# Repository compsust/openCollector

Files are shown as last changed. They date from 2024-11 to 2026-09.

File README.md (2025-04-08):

# OpenCollector - Open Source Data Collection

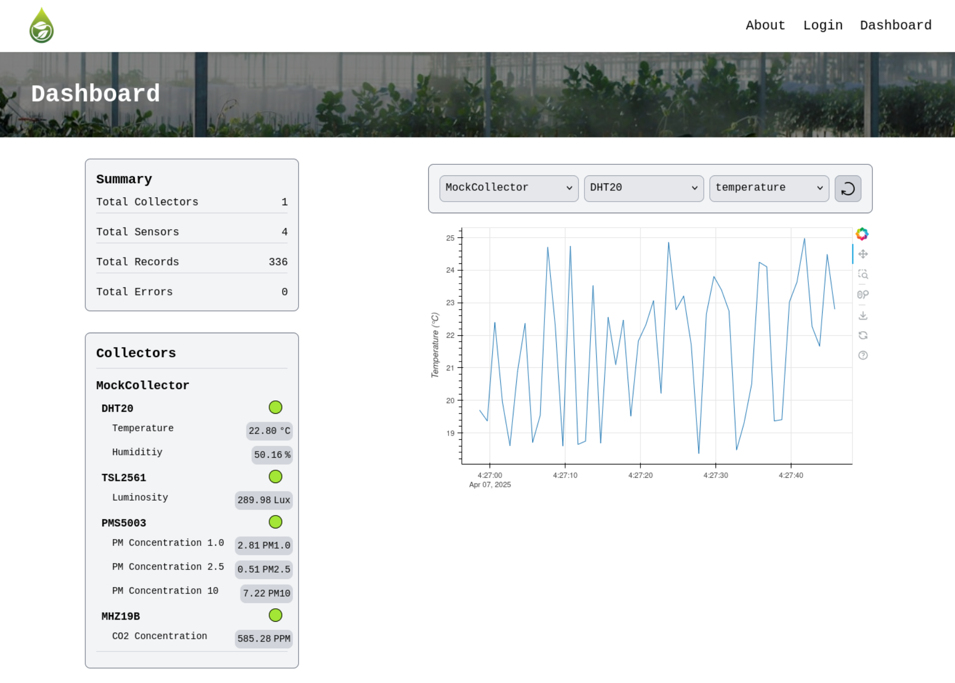
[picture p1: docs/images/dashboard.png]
Alt: a screenshot of the data monitoring dashboard


<div  align="center">
    <a href="https://compsust.fas.sfu.ca/openCollector/">
        <b>Documentation</b>
    </a>
</div>
</br>

OpenCollector is an open source Raspberry-Pi based data collection platform. Partnered with the [Simon Fraser University Computational Sustainability Lab](https://compsust.fas.sfu.ca/), this project is intended to create the foundation for a user-friendly IoT system that allows individuals and organizations to safely measure the impacts on their environment and monitor them for analysis and forecasting.

This prototype allows users to identify various parameters in their environment (such as temperature, light intensity, carbon dioxide) and tracks and displays the trends over time. This data is then securely stored in a cloud storage database to be able to access at a later date. While this prototype focuses on the use in a greenhouse, this project is intended for various uses.

## Usage and Development

Refer to [the documentation](https://compsust.fas.sfu.ca/openCollector/) for instructions on how to use and contribute to the project.

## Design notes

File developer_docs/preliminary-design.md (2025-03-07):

# Preliminary Software Design Document

This is the first software design document that is trying to establish what Python modules will be required and how they will interact with eachother. To start with, here is a brief overview of a principal used for design.

## Abstract Interfaces

In software engineering, an interface is a piece of code that contains only specification. For example, a function may define the arguments it accepts, the type of value it returns, and have a documentation string, but the actual workings of the function are left blank. The advantage of using interfaces is that it allows seperate pieces of software to be agnostic to specific implementations of the code they depend on, by making them depend on a contract instead. This allows changing those pieces independently. If one piece of the software changes, the changes required to make the rest of the system interact with the new logic should be as limited as possible to the location of the relevant change.

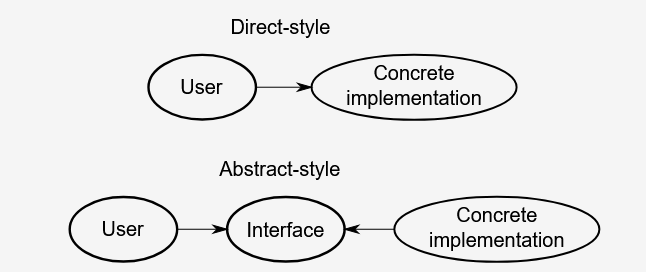
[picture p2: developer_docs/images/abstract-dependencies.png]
Abstract Interfaces Diagram


Abstract classes may be implemented with Python's `abc` (abstract base class) or `Protocol` types.

## Manager/Driver Design Pattern

The design pattern in use here can be called the Manager/Driver pattern. In this pattern, manager classes are responsible for implementing the main logic of the program, with the core control loop having access to all the manager classes it needs to acomplish its tasks, and deferring most of the logic to them. Manager classes focus more on high-level orchestration logic such as coordinating tasks whereas driver classes focus on low-level logic such as interfacing with hardware.

Manager classes may contain multiple driver classes which it uses to complete tasks. If required, the driver classes may be made to implement an abstract interface, such that the manager need not know the underlying workings of the driver. For example, the SensorManager class is what the main control loop of the program uses to retrieve sensor data. The SensorManager contains multiple SensorDriver classes, which each implement an AbstractSensorDriver interface. Because of this, if a new sensor is to be supported, this should not involve any changes to the SensorManager class, as it is only responsible for coordinating instances of classes which implement the AbstractSensorDriver interface. Therefore, only a new implementation of the AbstractSensorDriver interface would need to be created.

## Collector Node Design

This section goes over the software architecture of the collector node. A summary of this architecture is given in the following image.

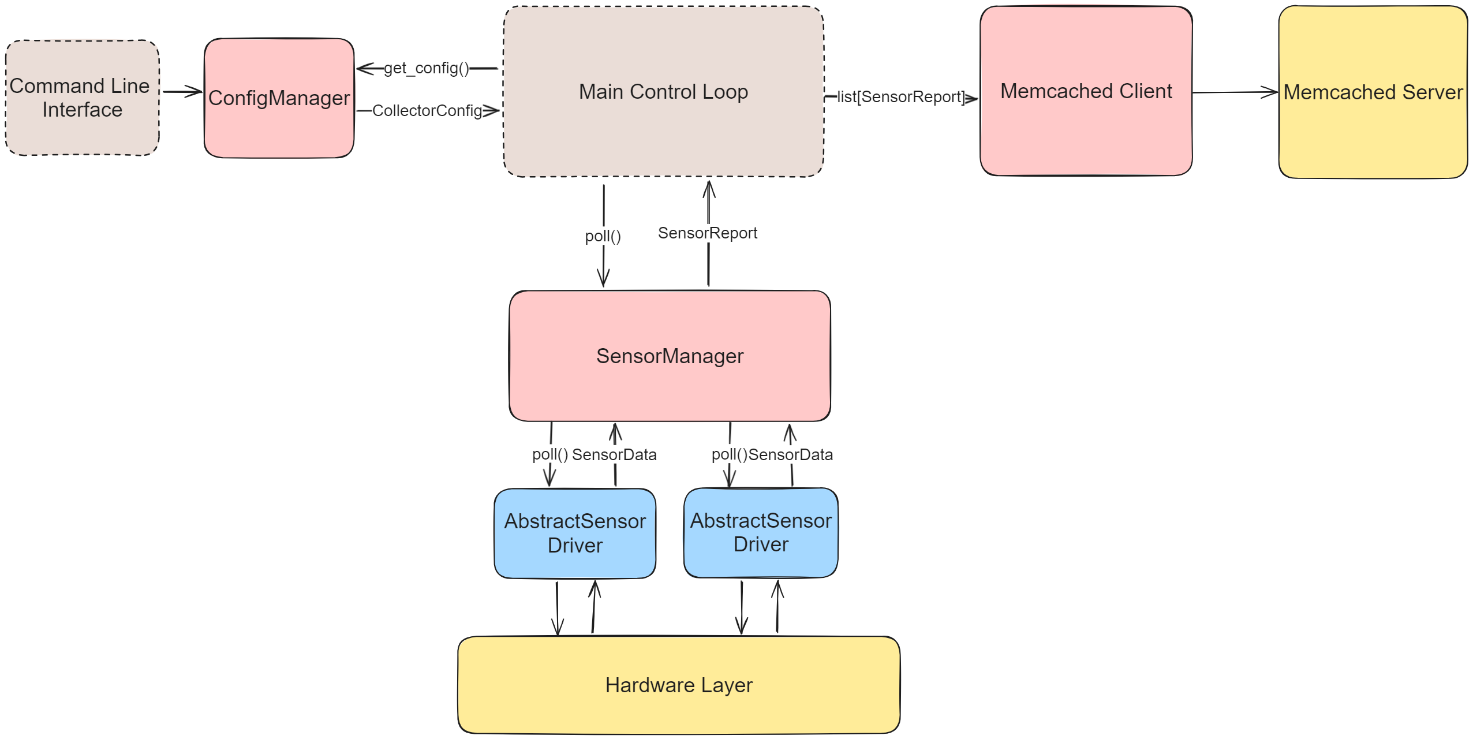
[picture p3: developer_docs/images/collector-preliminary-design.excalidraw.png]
Collector Node Design


### Classes

This section gives an overview of the components of the system.

#### Sensors

The `SensorManager` class is responsible for controlling each `SensorDriver` class it is connected to, and constructing a `CollectorReport` object. This will involve the following methods:
- `SensorManager.init()`: Given a `CollectorConfig` object, initializes a `SensorDriver` class for every sensor in the config. There will be a lookup table mapping types of sensor configurations to implementations of the `AbstractSensorDriver` interface which the `SensorManager` can use.
- `SensorManager.poll()`: Calls the `poll()` method on each of the underlying drivers, retrieving the data, catching any exceptions, and constructing a `CollectorReport` object to return to the main control loop.

The `AbstractSensorDriver` class is resposible for collecting data from the hardware and will contain the following methods:
- `SensorDriver.init()`: Given a `SensorConfig` object, initializes any underlying library with the configured values.
- `SensorDriver.poll()`: Calls the underlying sensor library to return a `SensorData` object.

#### Data Caching

This class will wrap an instance of the memcached client and allow the collector node to push data.

This class will simply have one method which stores any given data in the memcached client.
- `CacheManager.cache()`: Stores the data in-memory.

#### Configuration

The `ConfigManager` serves to make changes to the configuration file in a consistent way. If the configuration file is updated manually, there is no way to enforce constraints, such as GPIO pin numbers being correct.
- `ConfigManager.add_sensor()`: Adds a `SensorConfig` to the configuration file.
- `ConfigManager.update_sensor()`: Updates a `SensorConfig` in the configuration file.
- `ConfigManager.delete_sensor()`: Removes a `SensorConfig` from the configuration file.
- `ConfigManager.add_target()`: Adds a `TargetConfig` to the configuration file.
- `ConfigManager.update_target()`: Updates a `TargetConfig` in the configuration file.
- `ConfigManager.remove_target()`: Removes a `TargetConfig` from the configuration file.

### Data Structures

This section outlines the data structures that will need to be used and passed around the various components.

#### Sensor Data

These datastructures may utilize Python's dataclasses.

- `SensorData`: Generic data type for data returned by a sensor. May just be an alias for `Dict[str, Any]`.
- `CollectorRecord`: Contains a `SensorData`, the ID of the associated sensor, and a `datetime` timestamp.
- `CollectorError`: Contains an error code, an error message, the ID of the associated sensor, and a `datetime` timestamp.
- `CollectorReport`: Contains a list of `CollectorRecord`, a list of `CollectorError`, and the ID of the collector node.

#### Configuration Data

These datastructures may utilize the Pydantic library to make declarative validation easy. 

- `SensorConfig`: Contains an enumerated value describing the type of sensor, a sensor ID, and a dictionary containing any device-specific configuration values, such as GPIO pins and settings passed into the underlying sensor library.
- `TargetConfig`: Contains an ID of a storage node that data is to be sent to, and an endpoint where the data can be sent over the network.
- `CollectorConfig`: Contains a list of `SensorConfig`, a list of `TargetConfig`, and a collector node ID.

### Program Logic

#### Startup

Upon program startup, the main control loop does the following:
1. Instances of all required Manager classes are created.
2. The main control loop retrieves the device configuration by calling `ConfigManager.get_device_config()`. This configuration data contains all sensors that are currently configured on the device. For each sensor, the `SensorManager` initializes the corresponding `SensorDriver` class.

#### Polling

On an interval known as `POLLING_INTERVAL`, the following occurs:
1. The main control loop calls `SensorManager.poll()` which in turn calls `AbstractSensorDriver.poll()` on all the `SensorDrivers`. Each `SensorDriver` may return a `SensorData`, or it may raise an exception if an error has occurred. If it raises an exception, the `SensorManager` catches it and creates a `CollectorError` object. If it returns data, the `SensorManager` creates a `CollectorRecord`.
2. The `SensorManager` creater a `CollectorReport` object with the `CollectorRecord` and `CollectorError` objects, and populates it with the list of target storage node IDs that the device is to send data to. This is to allow the device to keep track of which of its targets it has sent data to, in the case that data is attempted to be sent when some connections are offline.
3. Finally, the `SensorManager` returns the `CollectorReport` object to the main control loop, which then calls `CacheManager.cache()` which stores the data in-memory.

## Storage Node Design

This section goes over the software architecture of the storage node. A summary of this architecture is given in the following image.

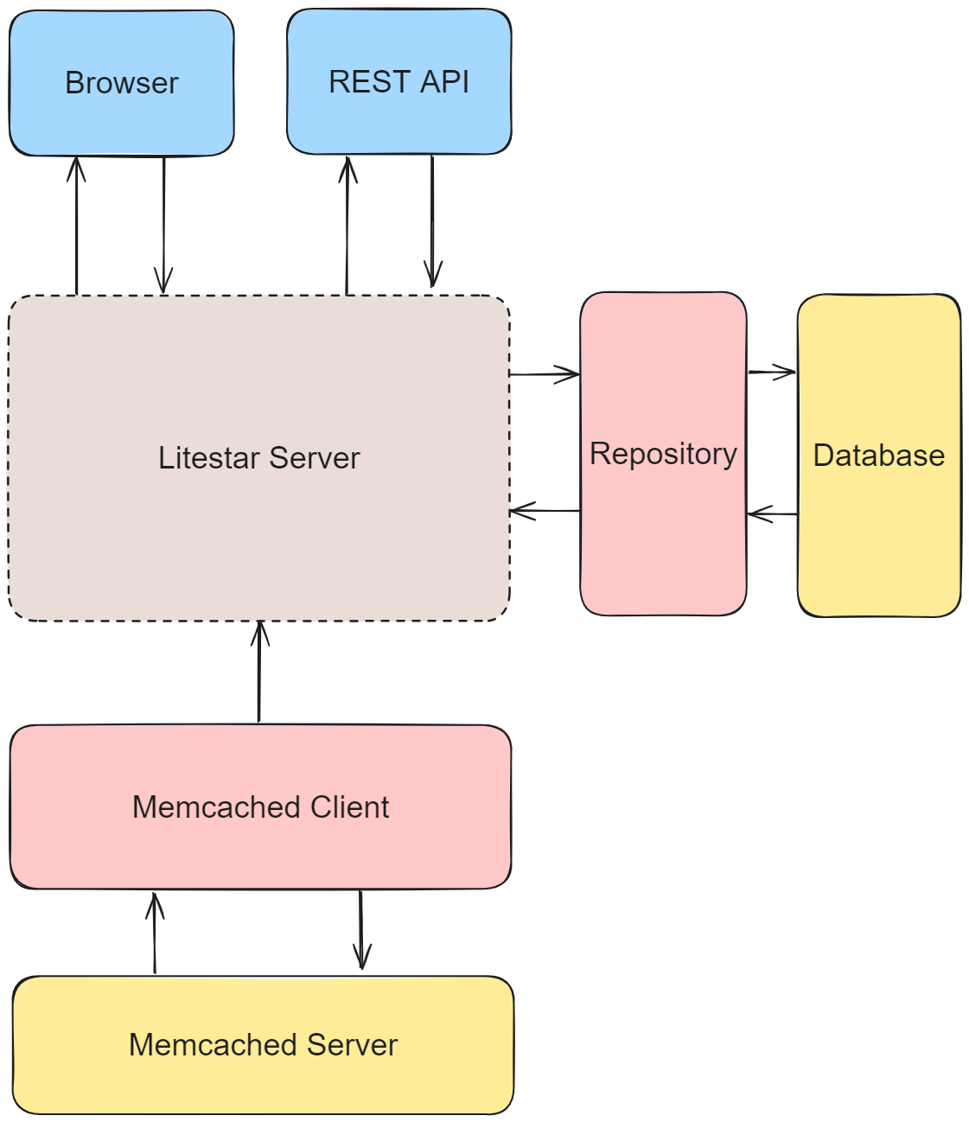
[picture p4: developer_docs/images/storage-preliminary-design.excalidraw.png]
Storage Node Design


### Classes

This section gives an overview of the components of the system.

#### Memcached Client/Server

The Memcached server is what is connected to the network and collecting the data cached by all connected collector nodes. It is run in a seperate process to the main Litestar server. The Memcached client is a construct initialized on the Litestar server which interacts with the Memcached server and pulls data from it. Via a regular task, the Litestar server pulls data from the Memcached server where it then stores it into persistent storage.  

#### Repository/Database

The database is the persistent storage mechanism and may be a SQL database such as Postgres or a no-SQL database such as MongoDB. The Litestar server should be agnostic to the underlying database technology through the use of the Repository class, which converts between database constructs and native application datatypes such as `CollectorReport`.

#### Litestar Browser & REST Interface

The Litestar app exposes two types of routes: those which return HTML and make up the interactive browser based user-interface, and those which return JSON which make up the REST API.

The browser app may make use of templating libraries such as Jinja2 to construct the HTML to be sent to the browser. With this approach, the HTML page is sent upon every request to the server in the style of a multi-page-app, and a library such as HTMX can be used to surgically update HTML elements to provide page updates without refreshes. However, if more complicated behavior is required, a javascript framework which can compile to HTML and JS such as the Svelte framework may be used instead.

The REST API will implement the REST standards for API development and thus represent collector and sensor data as resources to be queried via GET requests.

Both the API and browser app will use session authentication. An admin user will be created upon initialization of the storage node, and this admin user may create more users through a configuration page, bypassing the need for user registration.

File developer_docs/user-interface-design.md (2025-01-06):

# User Interface Design

This document summarizes the wireframes that were made to draft the user interface.

The wireframes follow this hierarchical structure for accessing in the browser:

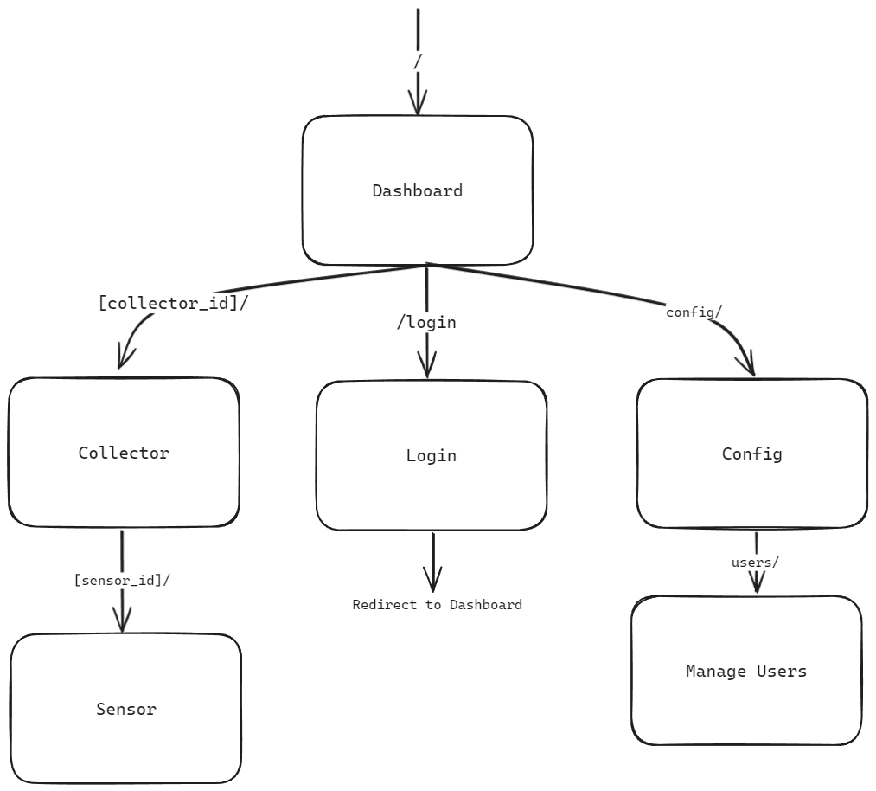
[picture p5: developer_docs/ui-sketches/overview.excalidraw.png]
Page Structure


The dashboard provides quick access to all information and a graph:

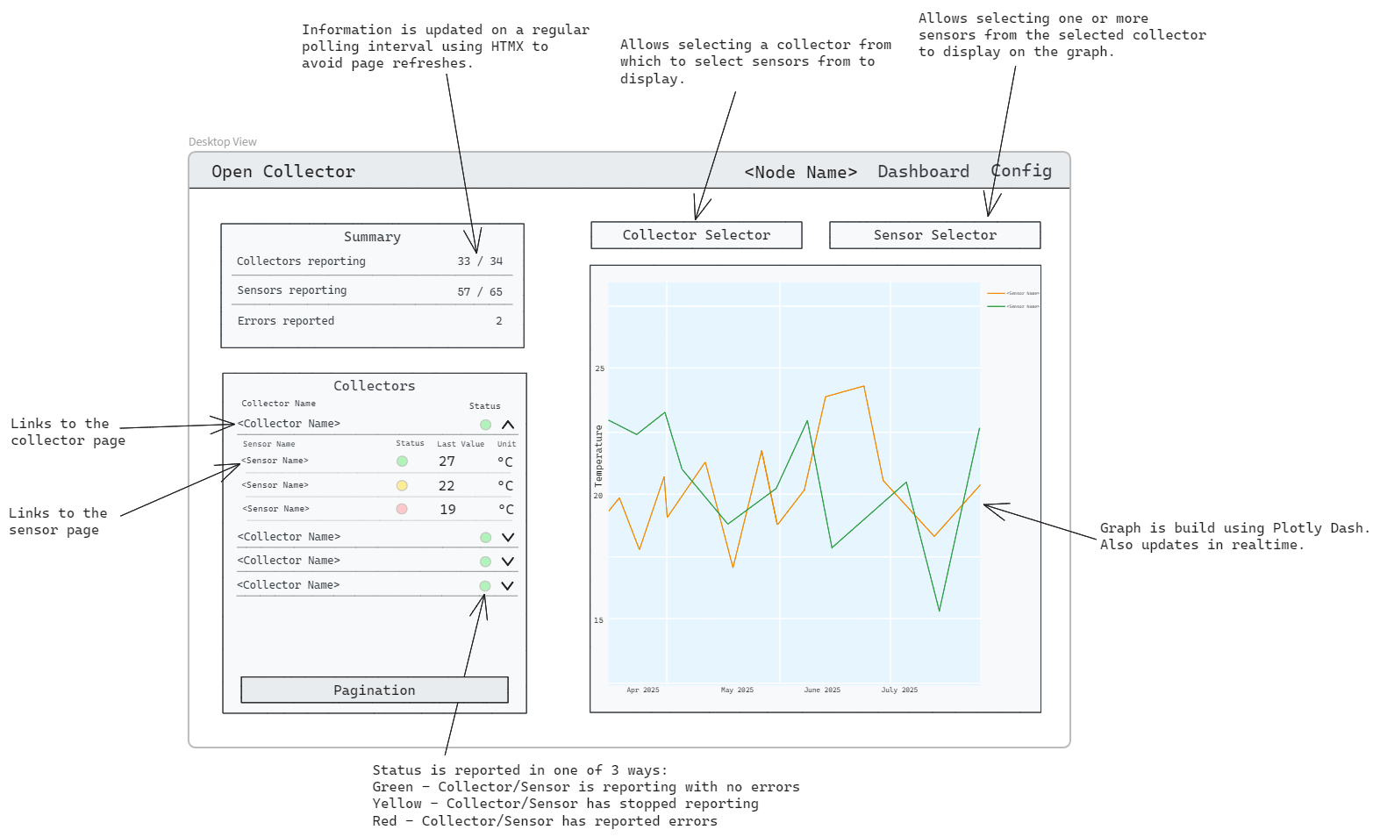
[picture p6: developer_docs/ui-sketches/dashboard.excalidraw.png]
Dashboard


The login page is used to authenticate the user. There is an admin user setup upon initialization of the storage node and more users can be configured by the admin user. If an unauthenticated user visits any page other than the login page, they are redirected to the login page. Upon successful login, the user is redirected to the login page.

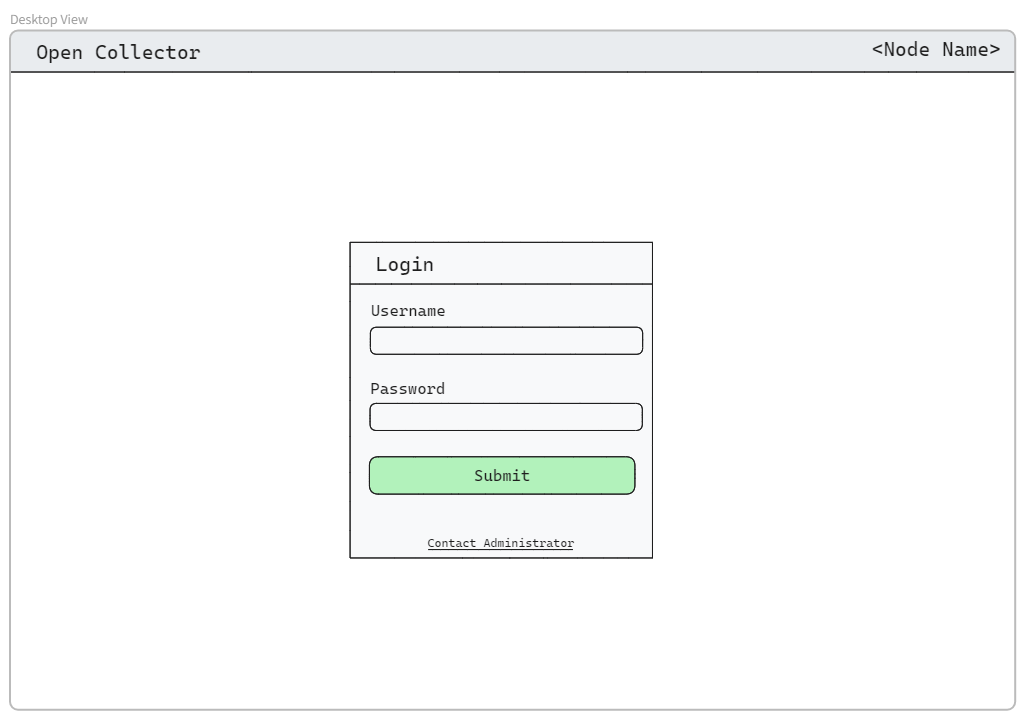
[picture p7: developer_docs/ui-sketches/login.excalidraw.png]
Login


Each collector has its own page, showing its details, sensors, and errors.

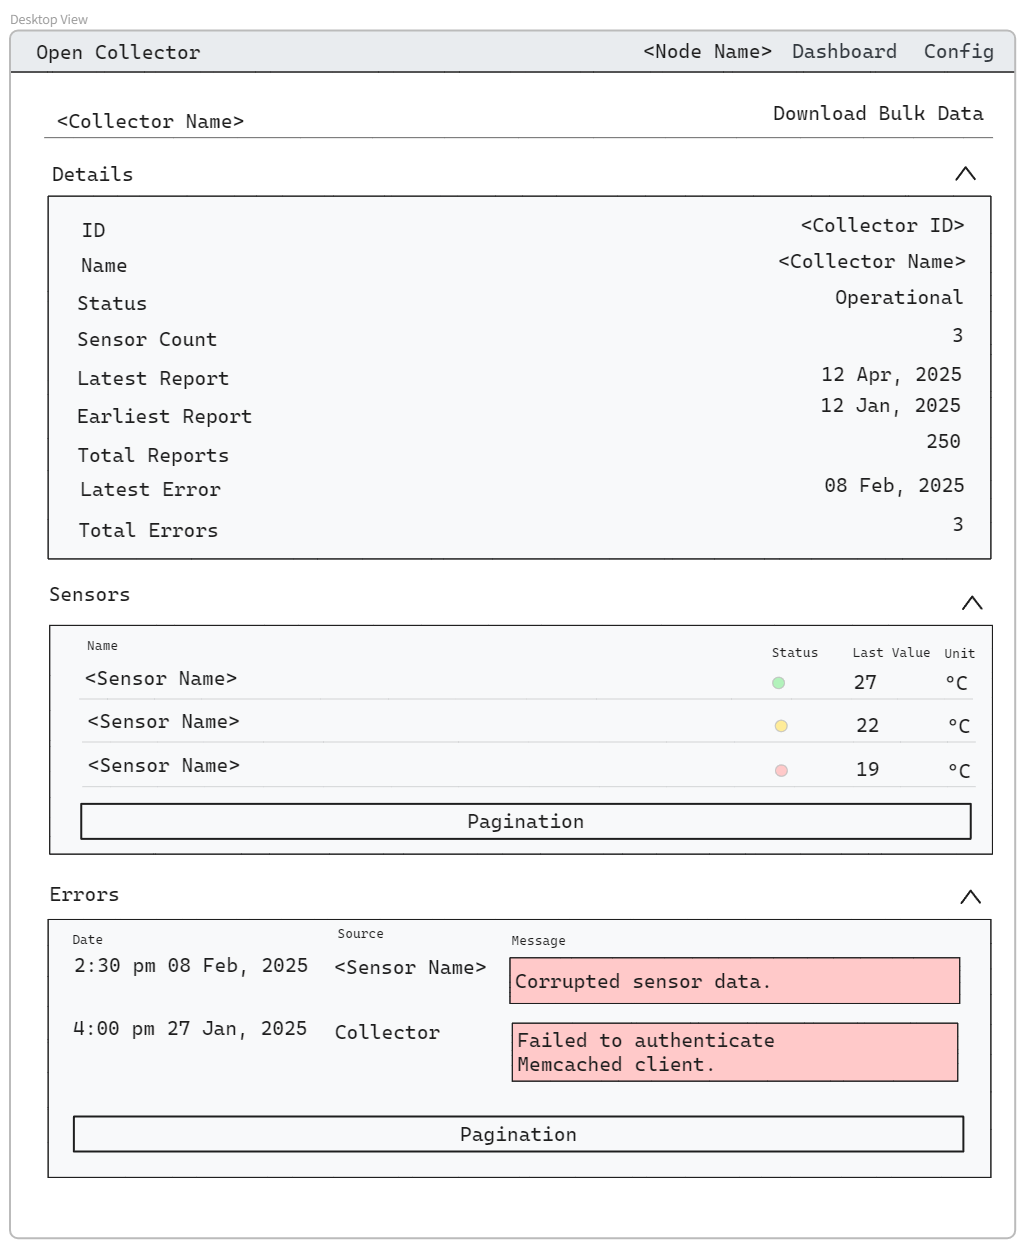
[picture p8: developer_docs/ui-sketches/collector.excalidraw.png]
Collector


Each sensor has its own page, showing its details, records, and errors.

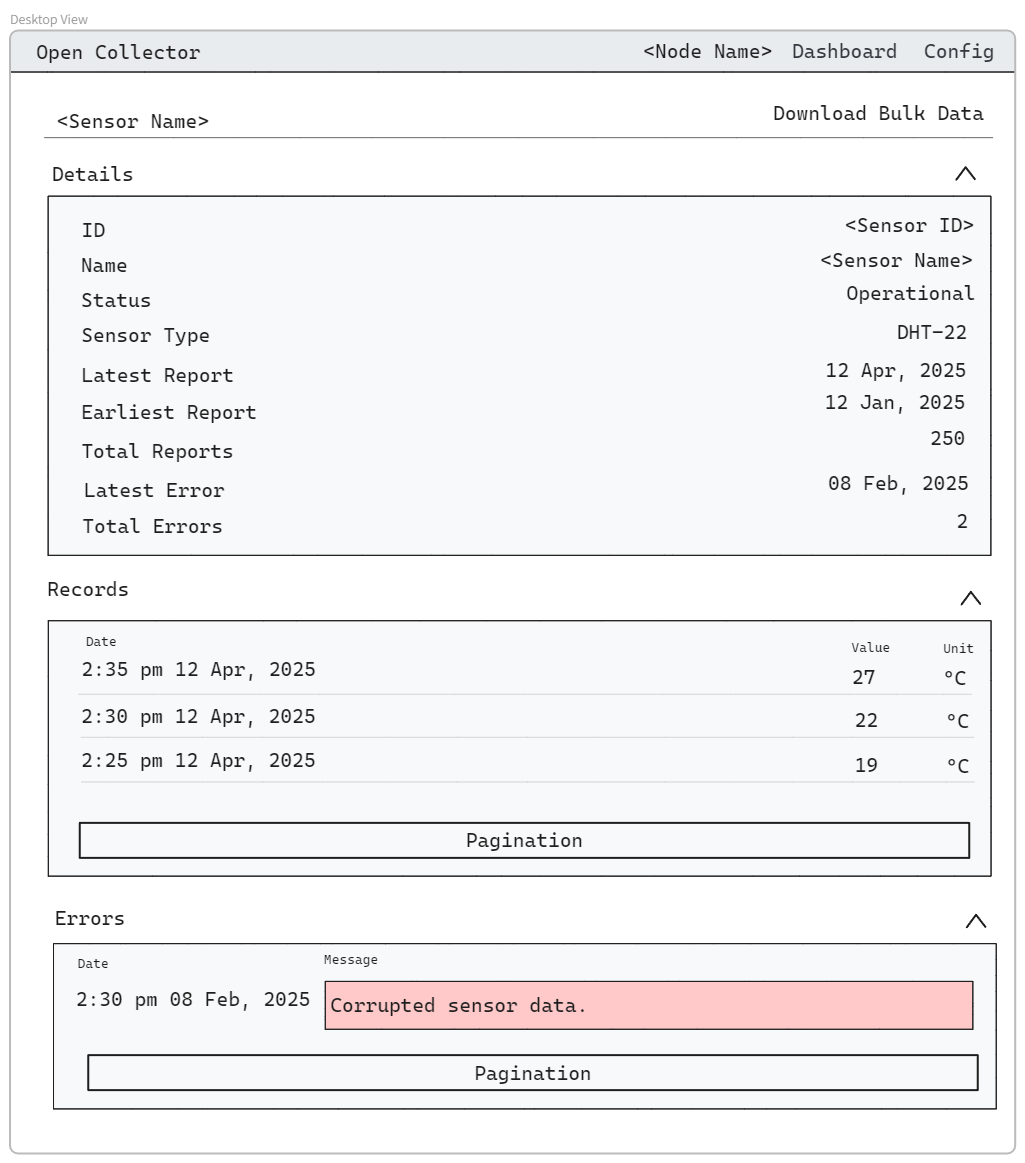
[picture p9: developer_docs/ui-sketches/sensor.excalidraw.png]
Sensor


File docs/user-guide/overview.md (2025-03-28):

# User Guide

This section of the documentation provides instructions for setting up and using the OpenCollector system to collect data.

## Identify Devices

The first step to deploying the OpenCollector stack is to determine which devices will be hosting which services. The following considerations apply.

- **Collector** nodes may be deployed on any device capable of reading from sensors and connecting to the internet. All collector code is compatible with *[micropython](https://micropython.org/)*, meaning the collector program may be run on a compatible microcontroller such as a Raspberry Pi Pico W. 
- **Storage** nodes may be deployed on any device that is capable of hosting a webserver. It may be run on the same device as the collector node, provided that the collector node is not running using *micropython*, as the storage node code is not compatible with *micropython*.
- **QuestDB** may be hosted on the same device as the **Storage** node, however the device must be capable of storing the desired volume of data at the desired intake bandwidth. If a large amount of data is to be stored, or many simultaneous collector streams are required, it may be best to host the database instance on a seperate device or on the cloud.

A list of which sensors are supported by the software is contained within the [Sensors](./collector/sensors.md) page. 

### Network Considerations

The database is required to be reachable over the network by both the collector and storage nodes. The collector nodes use *HTTP* to upload their data, and the storage node uses *HTTP* to display the user interface in the browser. The storage node uses the *PostgreSQL* protocol for reading data from the database, which by default uses *TCP/IP*.

## Deploy QuestDB and Storage Node

QuestDB and the storage node may be deployed together or seperately. The instructions included below support deploying them through *Docker* or through manual installation.

### Together

The following instructions are for self-hosting QuestDB together along with the storage node on the same device.

#### Docker

*TODO*

#### Manually

*TODO*

### Seperate

The following instructions are for hosting QuestDB seperately from the storage node.

#### QuestDB

Instructions for installing QuestDB are included in its [documentation](https://questdb.com/docs/quick-start/#install-questdb).

#### Docker

*TODO*

#### Manually

*TODO*

## Assemble Collectors

The wiring used to connect each collector node to its sensors, as well as how each collector node is situated in its environment, does not affect the operating of the system and thus may be achived however the user wishes. However, this project includes both a PCB that may be used to facilitate clean wiring of multiple sensors to a Raspberry Pi Pico W, as well as a 3D printable enclosure. See the [PCB and Enclosure](./collector/pcb.md) page for more information. 

## Configure Collectors

Each collector must be configured with the information required to connect to its sensors and upload its data. See the [Collector Config](./collector/config.md) for information on how to configure a collector.

## Deploy Collectors

*TODO*

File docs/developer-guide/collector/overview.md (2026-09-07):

# Collector Development

The main goals of the collector code are as follows:

- Be flexible in supporting the addition of new types of sensors to the software.
- Provide enough configuration options to support all use cases without modifying the source code.
- Support Micropython.

## Architecture

The architecture of the collector code is visualized below and contains the following modules:

- **Main Control Loop** - This is the entrypoint of the program and is responsible for orchestrating the modules and the endless loop.
- **`ConfigManager`** - This class is responsible for parsing and validating the configuration contained within `config.json`.
- **`UploadManager`** - This class is responsible for formatting the collected data and uploading it via HTTP to the configured QuestDB endpoint.
- **Sensor Polling**:
    - **`SensorDriver`** - Each `SensorDriver` class instance is responsible for collecting data from a single sensor.
    - **`SensorManager`** - This class is responsible for initializing as many `SensorDriver` instances as are called for in the configuration, polling them, and sending the data to the main control loop.

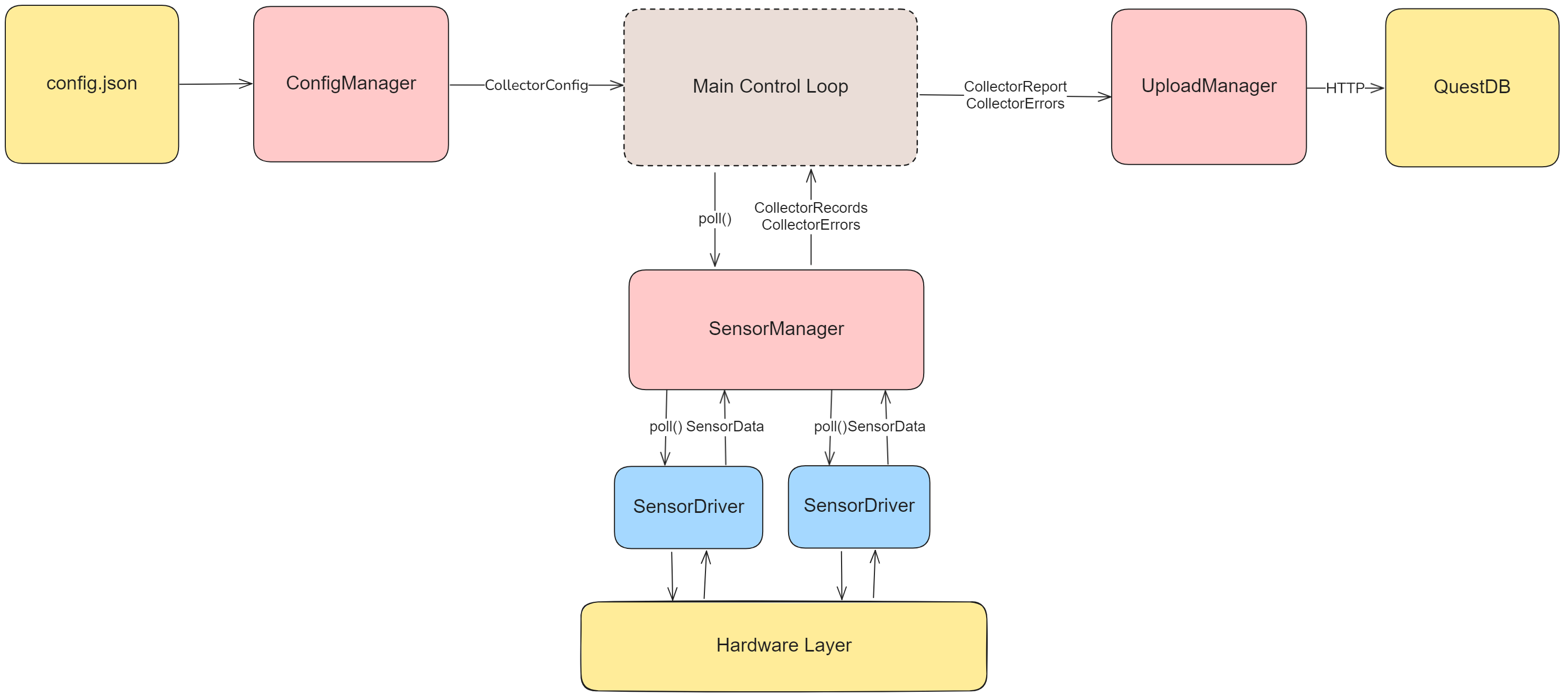
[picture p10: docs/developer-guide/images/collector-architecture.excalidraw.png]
Alt: the diagram visualizes the ConfigManager sending the configuration to the main control loop, the SensorManager polling multiple SensorDrivers which each communicate with the hardware layer, and the UploadManager sending the data to the QuestDB database


### Main Control Loop

The main control loop has the following behavior:

1. Initializes all required manager classes.
2. Updates the metadata tables in the database with the currently collector and sensor configuration.
3. On an endless loop:
    1. Collects sensor data.
    2. Uploads sensor data.
    3. If the upload fails, logs the exception locally and proceeds to the next cycle; the failed report is not retried.
    4. Waits for the configured `polling_interval`, expressed in milliseconds.

```mermaid

stateDiagram-v2
    [*] --> Initialization

    Initialization --> Metadata : Success
    Metadata --> Poll: Success
    Initialization --> Error : Failure
    Metadata --> Error : Failure
    Poll --> Upload
    Upload --> Wait
    Wait --> Poll : After Polling Interval

    Metadata: Metadata Upload
    Upload: Data Upload
```

### Config

For documentation on what the configuration values do, see the [User Guide](../../user-guide/collector/config.md).

See the [Config Reference](./reference/config.md) for documentation on the configuration-related source code.

### Upload

For documentation on the structure of the database, see the [Storage Database](../storage/database.md) page.

See the [Upload Reference](./reference/upload.md) for documentation on the upload-related source code.

### Sensors

For documentation on which sensors are currently supported and how to configure them, see the [User Guide](../../user-guide/collector/sensors.md) sensors page.

For instructions on how to add support for new sensors, see the [Sensor](./sensors.md) page.

See the [Sensor Reference](./reference/sensors.md) for documentation on the sensor-related source code.

#### Architecture & Approach

As the main goal of the sensor code design was to support adding more sensors in the future, the sensor code follows a manager-driver pattern, with the driver code fulfilling an abstract interface.

In software engineering, an interface is a piece of code that contains only specification. For example, a function may define the arguments it accepts, the type of value it returns, and have a documentation string explaining its behaviour, but the actual workings of the function are left blank. The advantage of using interfaces is that it allows seperate pieces of software to be agnostic to specific implementations of the code they depend on, by making them depend on a contract instead. This allows changing those pieces independently. If one piece of the software changes, the changes required to make the rest of the system interact with the new logic should be as limited as possible to the location of the relevant change.

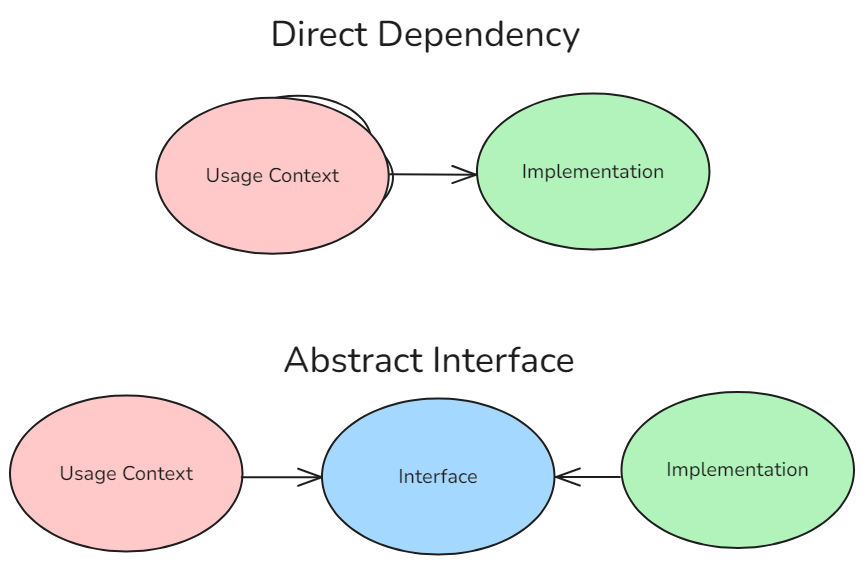
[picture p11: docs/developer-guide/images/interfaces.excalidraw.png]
Alt: the use of abstract interfaces is visualized by the usage context and the implementation both being dependent on the same dependency, as oppsed to the usage context being directly dependent on the implementation


In practice, this means that that the `SensorManger` class is not directly dependent on any specific implementation of a sensor but is instead dependent on an interface called `AbstractSensorDriver`. As long as the interface is properly designed, the changes to the codebase required to add new sensors to the software should be isolated to the creation of new implementations of the interface.

Abstract classes are be implemented with Python's `Protocol` type.

## Development

The collector is designed to run under both CPython and MicroPython. Packaging is automated, while deployment on physical hardware remains experimental and must be validated with the target sensors and firmware.

For development on a Raspberry Pi Pico W:

1. Flash a current Pico W MicroPython firmware image using the [Raspberry Pi documentation](https://www.raspberrypi.com/documentation/microcontrollers/micropython.html).
2. Copy `collector/src/config.example.json` to `collector/src/config.json` and replace the example IDs, network credentials, database address, GPIO assignments, and sensor settings.
3. Install `mpremote`, connect one board, and run `./scripts/flash_pico.sh collector/src/config.json` from the repository root.
4. Reset the board while a serial console is attached. Confirm initialization, metadata upload, repeated polling, and error reporting before disconnecting it.

Keep secrets and deployment-specific configuration out of version control. When changing collector code, test configuration parsing and sensor drivers under CPython first where practical, then repeat the test on real MicroPython hardware: module availability, filesystem paths, timing, and networking behavior differ between the runtimes.

The **Pico W package** workflow validates the canonical on-device layout without hardware. The manually dispatched **Pico W hardware-in-the-loop** workflow requires a self-hosted runner labelled `self-hosted`, `micropython`, and `pico-w`, plus a `PICO_CONFIG_JSON` repository secret. Record the MicroPython firmware version and attached sensor models with each physical test run.

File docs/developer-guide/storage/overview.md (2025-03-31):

# Storage Development

The main goals of the storage code are as follows:

- Provide a simple UI for reading the data returned by the collector nodes.
- Be stateless, such that multiple storage nodes can access the same database.

## Architecture

The architecture of the storage code is visualized below and contains the following modules:

- **Litestar** - The API framework in use for serving the browser and API interfaces.
- **Database** - This section contains code for initializing the database connection, structuring the tables, and querying the data.
- **API** - This section uses the Litestar framework to expose the database queries over a REST API.
- **Browser** - This section uses the Litestar framework to serve a visual user interface to browsers which updates in realtime.  

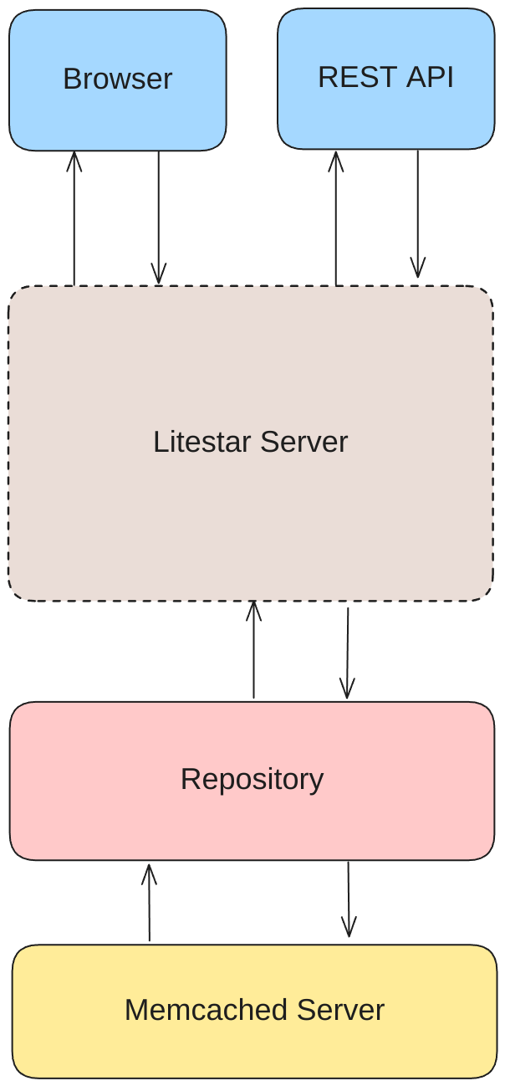
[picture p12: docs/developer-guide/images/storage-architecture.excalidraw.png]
Alt: the diagram visualizes the Litestar server reading data from the database and exposing it to a REST API and browser interface.


### Litestar

See the [Litestar documentation](https://litestar.dev/) for information on the web server framework in use

### Database

The database 

### API

### Browser

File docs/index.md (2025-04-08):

# OpenCollector - Open Source Data Collection

Alt: a screenshot of the data monitoring dashboard

OpenCollector is an open source Raspberry-Pi based data collection platform. Partnered with the [Simon Fraser University Computational Sustainability Lab](https://compsust.fas.sfu.ca/), this project is intended to create the foundation for a user-friendly IoT system that allows individuals and organizations to safely measure the impacts on their environment and monitor them for analysis and forecasting.

This prototype allows users to identify various parameters in their environment (such as temperature, light intensity, carbon dioxide) and tracks and displays the trends over time. This data is then securely stored in a cloud storage database to be able to access at a later date. While this prototype focuses on the use in a greenhouse, this project is intended for various uses.

The project encompasses the following parts:

1. Python code for collecting data from multiple sensors and uploading it to a database.
2. Python code for reading from a database and visually displaying data.
3. A PCB for wiring up a Raspberry Pi Pico W to a temperature, humidity, particulate matter, light, and CO2 sensor.
4. A 3D printable enclosure for securing the PCB.

## Documentation

See below for how to use this documentation:

- User Guide:
    - [Usage Instructions](./user-guide/usage.md): Instructions on how to use the system.
    - [Setup Instructions](./user-guide/setup.md): Instructions on how to set up the system.
- [Developer Guide](./developer-guide/overview.md): Technical details and design. 

## System Architecture

The OpenCollector system contains two main modules:      

1. **Collector Nodes** are the edge devices responsible for collecting data from sensors and uploading it to the database.
2. **Storage Nodes** are the cloud devices responsible for reading data from the database and displaying it in a cloud platform.

Additionally, the following pieces are required for the OpenCollector system to work:

- **[QuestDB](https://questdb.com/)** is used as the open-source timeseries database and is the glue between the collector and storage nodes.

Given a machine that is compatible with hosting a webserver and connecting to sensors, these modules may be run on the same device. If desired, they can be run on seperate devices, with the storage node and database on the same device or different devices, and the collector node run on an edge device connected to sensors.

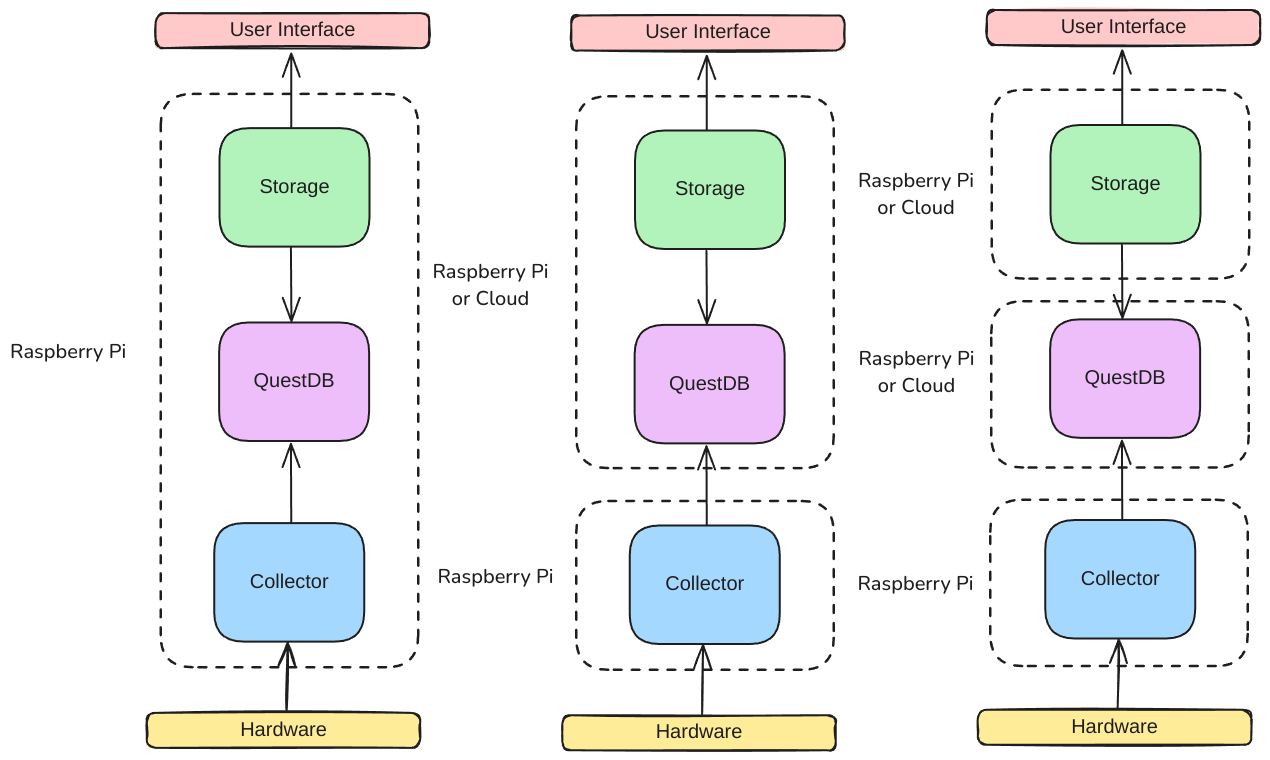
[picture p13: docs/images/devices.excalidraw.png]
Alt: a diagram visualizes that the collector, database, and storage nodes may be run on seperate or the same device.


Nodes may be connected together under the following rules:

1. Collector nodes have a single QuestDB database as a target.
2. An unlimited number of collector nodes may send data to a single QuestDB database.
3. An unlimited number of storage nodes may read data from a single QuestDB database.

This allows for any number of collector nodes to be used with a single database. While multiple storage nodes can be connected to a single database, since their only purpose is to display data, there may not be an advantage to this. Currently, a collector node can only send data to one database at a time.

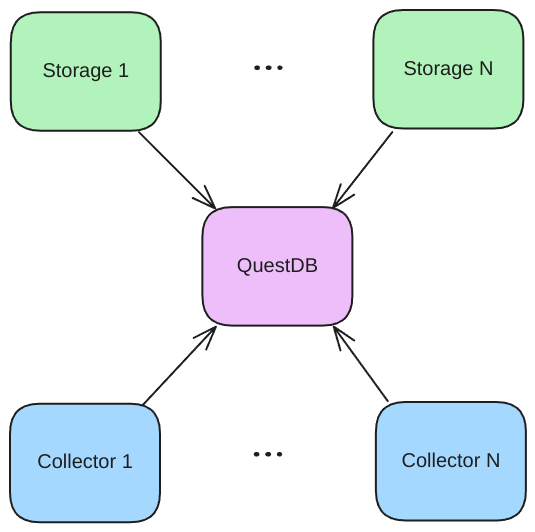
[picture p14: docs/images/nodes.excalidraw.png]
Alt: a diagram visualizes that any number of collectors and storages nodes can be connected to a single database
.

## Dependencies

This project makes use of the following dependencies:

- [Raspberry Pi](https://www.raspberrypi.com/) is used as the basis for computing, though the system should work with other hardware.
- [Python](https://www.python.org/) is used for all programming.
- [Micropython](https://micropython.org/) is used to write microcontroller compatible code for the collector node.
- [QuestDB](https://questdb.com/) is used as an open-source timeseries database.
- [Litestar](https://litestar.dev/) is used to create the REST API and browser user-interfaces.
- [HTMX](https://htmx.org/) for real-time HTML updates in the browser interface.
- [Material for MkDocs](https://squidfunk.github.io/mkdocs-material/) is used to create this documentation site.

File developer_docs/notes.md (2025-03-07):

Will want to create a readthedocs for this as well

Explain all the steps for supporting a new sensor:
1. Add a new value to SensorCodeEnum
2. Add a new entry to sensor_metadata
3. Create a new SensorDriver in the src/collector/sensors/drivers folder
4. Add this SensorDriver to the sensor_drivers dict in sensor_codes.py
5. Add the sensor config to config.json

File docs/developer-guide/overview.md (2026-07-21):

# Overview

Overall, the OpenCollector system is made up of two components:

1. A Python / Micropython program which reads sensor data and uploads it to a database on a loop.
2.  A Python webserver which reads data from the database and exposes it to a REST API and browser interface.

This developer guide provides technical details on how these components are set up and instructions on how to work on the codebase.

See the documentation sections for each sub-project:

- [Collector](./collector/overview.md)
- [Storage](./storage/overview.md)

## Project Structure

The project is split up into sections, each with one folder in the root of the repository:

- `collector` for the collector node code.
- `storage` for the storage node code.
- `common` for code common to the two nodes, such as metadata for the supported sensors.
- `docs` for this documentation site.

The [UV package manager](https://docs.astral.sh/uv/) is used to manage dependencies. A file called `pyproject.toml` is used to store metadata about the project such as its dependencies. There is a `pyproject.toml` file in the root of the repository, which specifies the dependencies used throughout the entire repository, as well as one `pyproject.toml` in each of the `common`, `storage`, and `collector` directories which specifies the dependencies required for each sub-project.

The `collector` and `storage` sub-projects both specify a local path dependency to the `common` directory.

The following commands are available using `uv`:

- `uv sync` - this installs the dependencies into the environment, and is run automatically after container creation.
- `uv sync --active` - because of the way `uv` handles depdendencies in sub-projects, to install the dependencies of a sub-project it may be required to navigate to the sub-project directory and run this so that `uv` installs the dependencies specified in the sub-project's `pyproject.toml` and not the one at the root of the repository.
- `uv add` - this is used to add a dependency to the `pyproject.toml`. Note that it will add the dependency to the sub-project the command is run in.
- `uv add --dev` - for development-only dependencies.
- `uv run <command>` - used to run commands made available by the dependencies installed by `uv` 
- `uv run ruff format` this runs the code formatter.
- `uv run ruff check --fix` this runs the code linter.

See the individual sub-project folders of this documentation for commands specific to each project.

## Environment Setup

The development environment may be set up manually or it may be produced using [Development Containers](https://containers.dev/). The benefit to using devcontainers is that reproduction of the environment, including a QuestDB instance, is easy and configurable. The downside is that docker is required to be running on your development machine, and support for IDEs other than VSCode is lacking.

Note that if you are only editing the documentation, no steps other than cloning the repository is needed as the documentation is build using a Github Action, however previewing the documentation does require installing the development dependencies. If you are just working on the collector code and don't need to test a database connection, you may skip using Docker and Devcontainers as the main advantage of that is easy installation of QuestDB.

### Devcontainer

[Development Containers](https://containers.dev/) allows the use of Docker containers as full-featured development environments.

#### Operating System

##### Windows

Using devcontainers on Windows requires Linux virtualization as Docker cannot run natively on Windows.

1. Install the [Windows Subsystem for Linux](https://learn.microsoft.com/en-us/windows/wsl/install). This may require changing Windows or Bios settings for virtualization.
2. Install Docker Engine through [Docker Desktop](https://www.docker.com/products/docker-desktop/). Start Docker Engine.

##### Linux

1. Install Docker Engine through [Docker Desktop](https://www.docker.com/products/docker-desktop/) or on its own. Start Docker Engine.

#### Editor

##### VSCode

1. Install [VSCode](https://code.visualstudio.com/) and the [Dev Containers](https://marketplace.visualstudio.com/items?itemName=ms-vscode-remote.remote-containers) extension.
2. Run the VSCode command `Clone repository into container volume.` and enter the name of the repository: `compsust/openCollector`. Cloning the repository into the container brings optimal performance, but if that doesn't work, clone the repository into a Windows folder and run the command in VSCode `Run folder in container.`

The container should display a terminal with no errors.

##### Other Editors

Devcontainers should work with other IDEs such as Neovim, but setup instructions aren't included here at this time.

#### Troubleshooting

- Is Docker Engine running?

### Manual

Use a manual environment when Docker is unavailable or when you only need one sub-project.

1. Install Git, Python 3.13 or later, and [uv](https://docs.astral.sh/uv/getting-started/installation/).
2. Clone the repository and install the root development dependencies:

    ```bash
    git clone https://github.com/compsust/openCollector.git
    cd openCollector
    uv sync --dev
    ```

3. When working on a sub-project, change into `collector` or `storage` and run `uv sync --active` so uv installs that sub-project's dependencies and its local dependency on `common`.
4. Install and start [QuestDB](https://questdb.com/docs/quick-start/) if the work requires database integration. Copy `storage/.env.example` to `storage/.env` and make its PostgreSQL connection settings match the QuestDB instance.
5. Run the checks used by the project before submitting a change:

    ```bash
    uv run ruff format --check .
    uv run ruff check .
    uv run mkdocs build --strict
    ```

To preview documentation locally, run `uv run mkdocs serve` from the repository root and open the address printed in the terminal. See the [user setup guide](../user-guide/setup.md) for starting the storage application and database.

## Supporting New Sensors

To add a new sensor to the software, see the instructions located in the [sensors page](./collector/sensors.md)

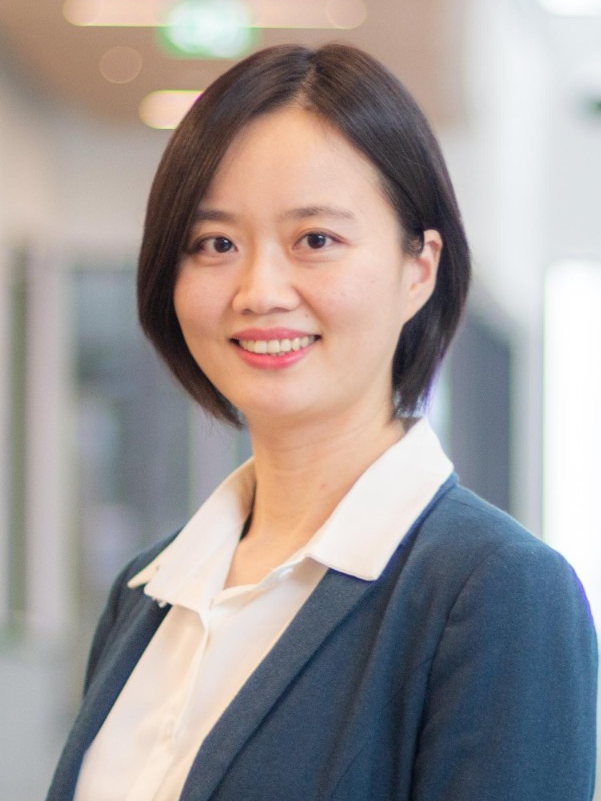
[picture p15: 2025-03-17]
Website_Development/images/mina_xu.png

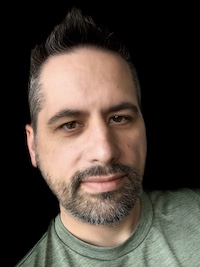
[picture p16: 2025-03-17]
Website_Development/images/stephen_makonin.jpg

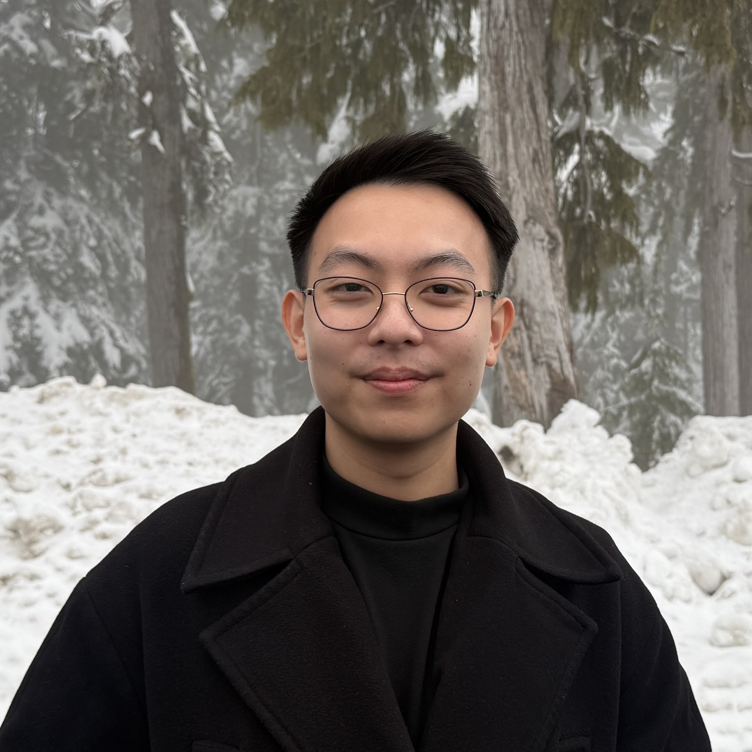
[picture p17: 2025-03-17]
Website_Development/images/william.jpg

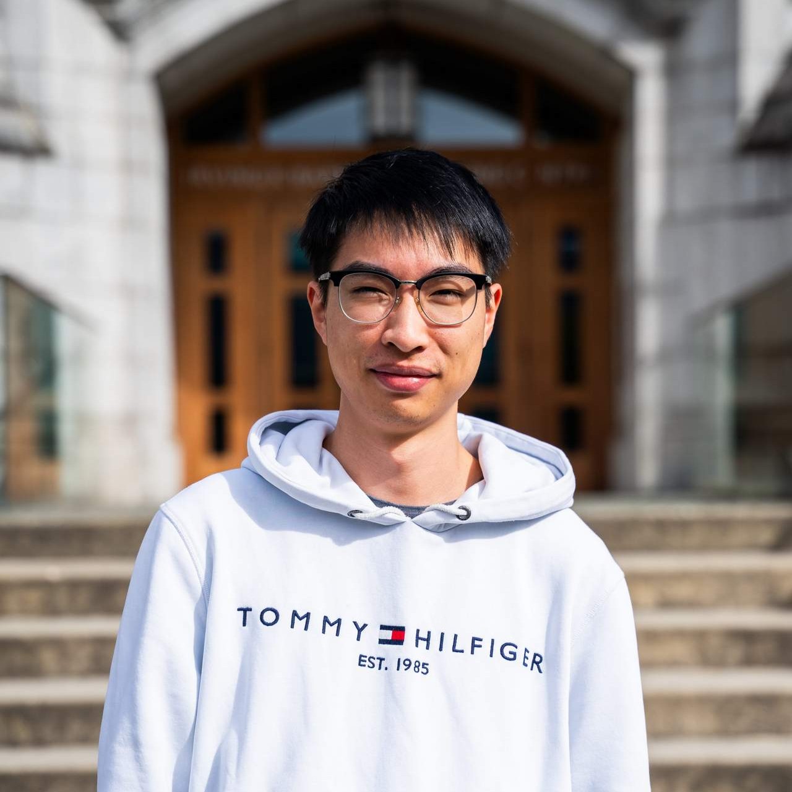
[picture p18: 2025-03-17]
Website_Development/images/micheal.jpg

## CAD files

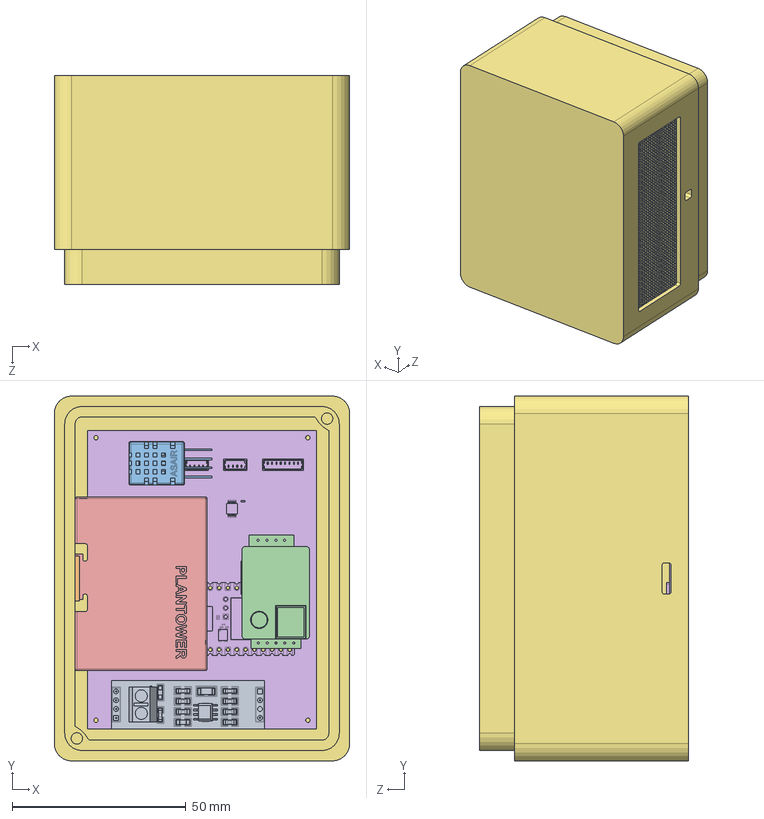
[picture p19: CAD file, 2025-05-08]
Enclosure_Design/Assem1.SLDASM
85.0 x 105.0 x 60.0 mm
PCB
PMS5003
MH-z19_c02
DHT20
TSL_2561
rs485

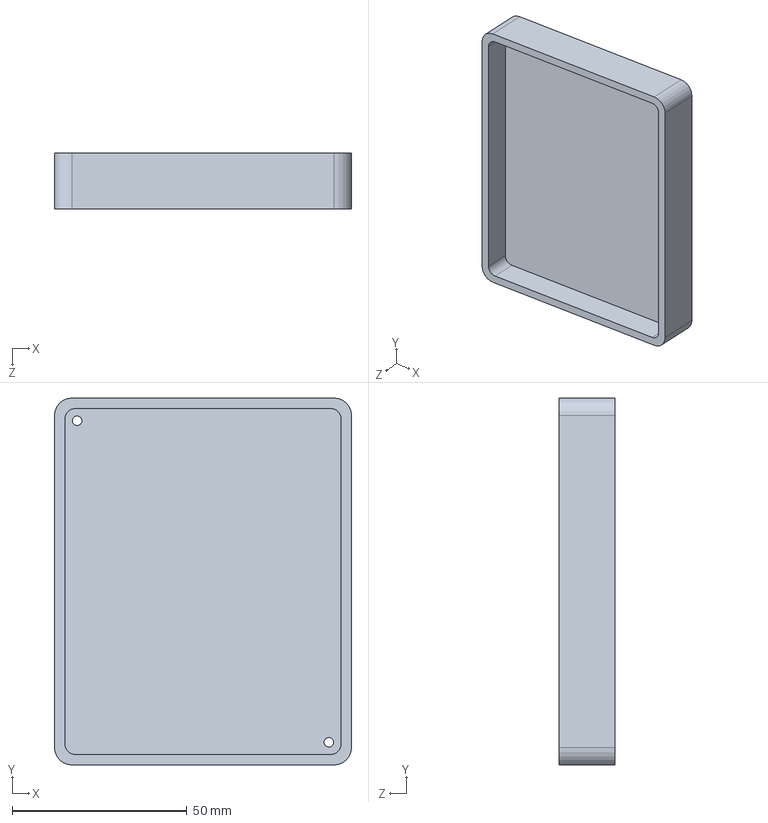
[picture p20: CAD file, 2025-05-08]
Enclosure_Design/Cap.SLDPRT
85.0 x 105.0 x 16.0 mm

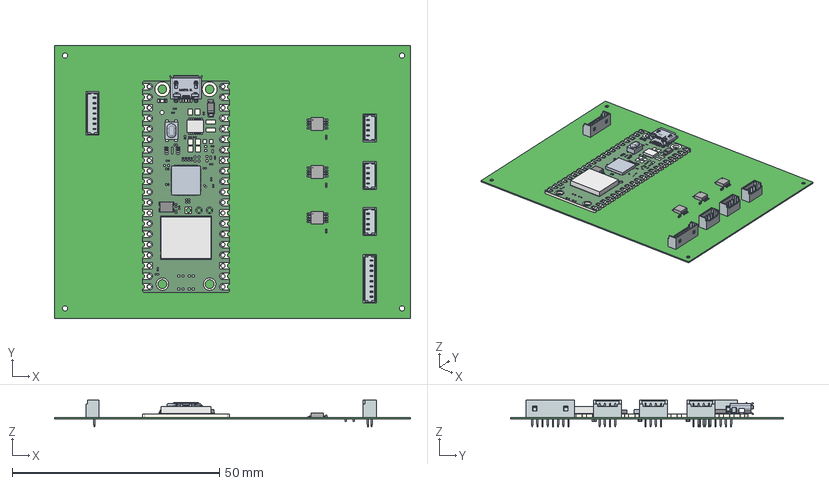
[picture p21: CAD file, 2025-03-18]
PCBs/Sensor Interface PCB REV4/PCB.step
85.9 x 65.8 x 6.50 mm
RES_CRCW_0402 x 9
SOLDERMASK_TOP
Dielectric
SOLDERMASK_BOTTOM
AVAGO_QSM
FCI_10103594-0001LF
RF_SHIELD_PICOW
RPI_RP2040
RT-WDFN-14AL
SOD123FL
TONEPARTS_TP-1221U-K9K5325
XTAL320X250X100

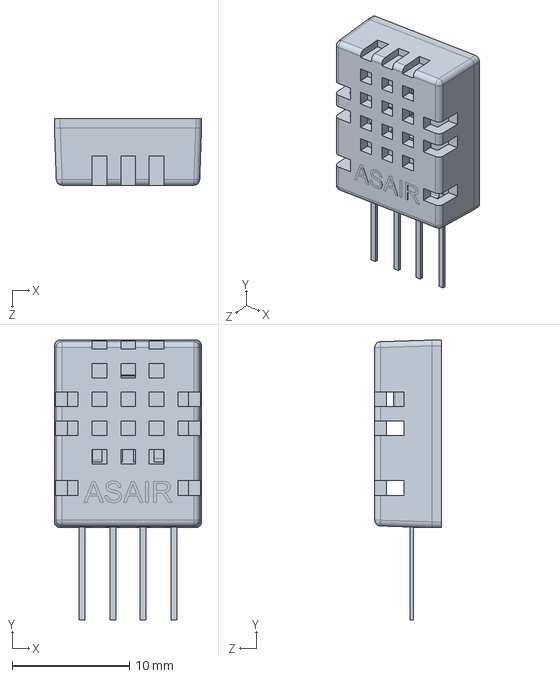
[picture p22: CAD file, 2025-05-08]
Enclosure_Design/DHT20.SLDPRT
12.5 x 23.9 x 5.70 mm

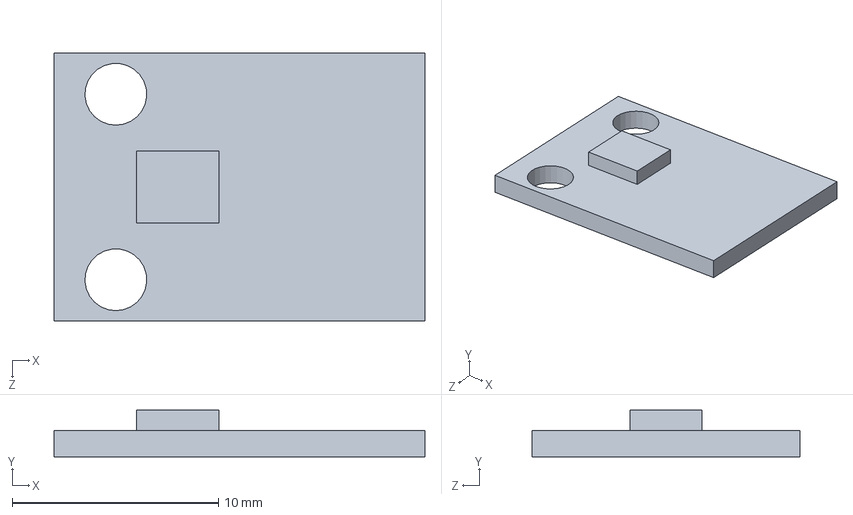
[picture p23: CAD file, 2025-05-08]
Enclosure_Design/TSL_2561.SLDPRT
18.0 x 2.27 x 13.0 mm

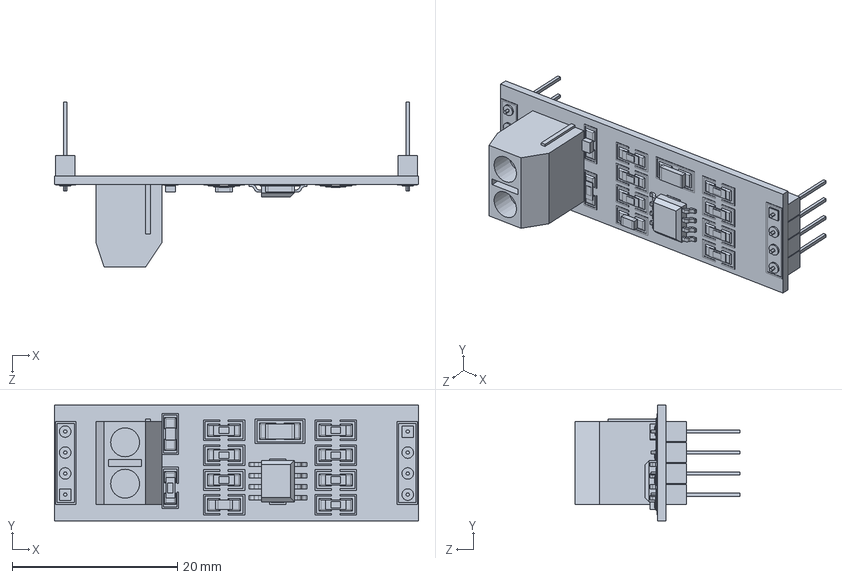
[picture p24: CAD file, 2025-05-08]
Enclosure_Design/rs485.SLDPRT
44.0 x 14.0 x 20.0 mm

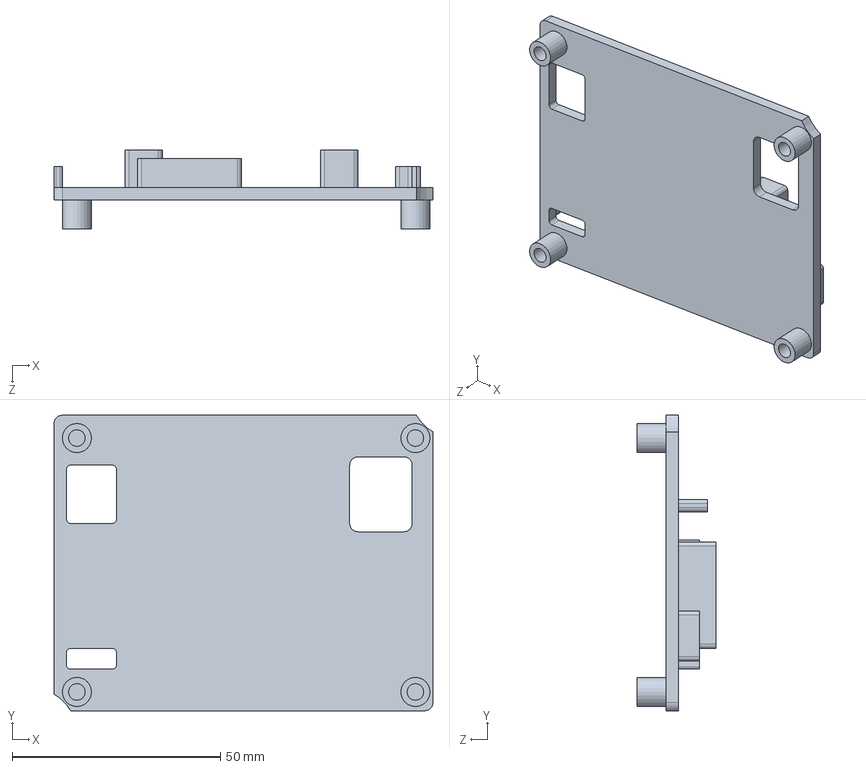
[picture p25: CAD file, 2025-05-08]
Enclosure_Design/Part2.SLDPRT
91.0 x 71.0 x 19.0 mm

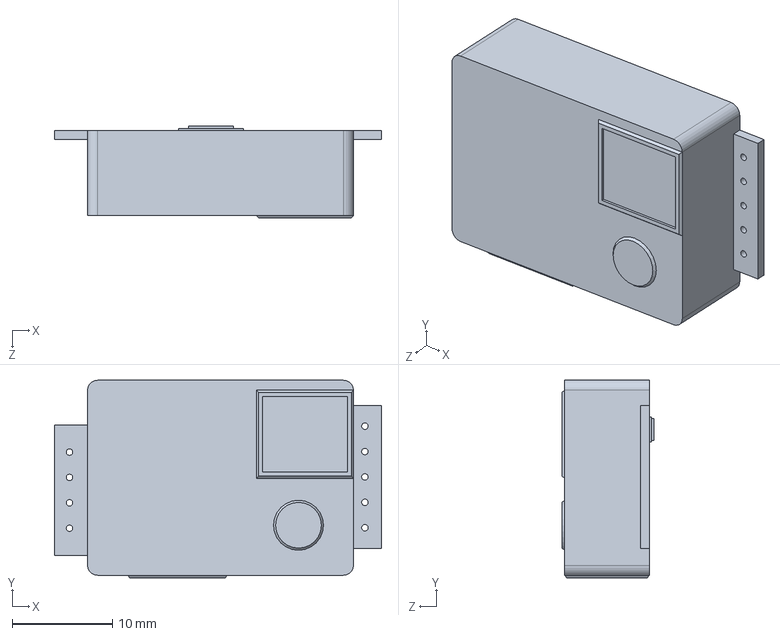
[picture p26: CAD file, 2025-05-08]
Enclosure_Design/MH-z19_c02.SLDPRT
32.7 x 19.8 x 9.20 mm

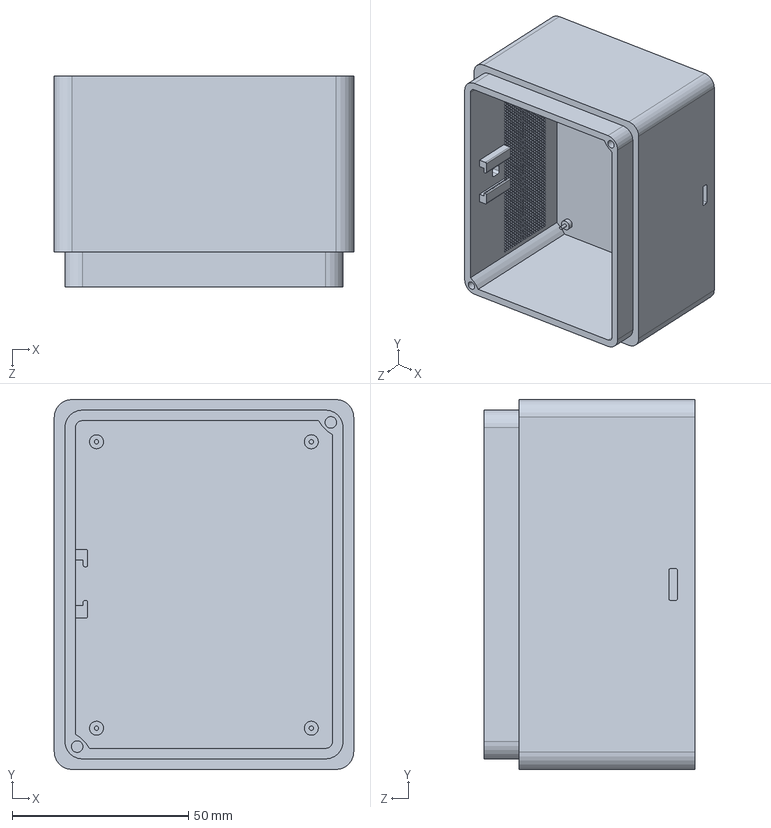
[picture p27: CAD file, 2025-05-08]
Enclosure_Design/Part1.SLDPRT
85.0 x 105.0 x 60.0 mm

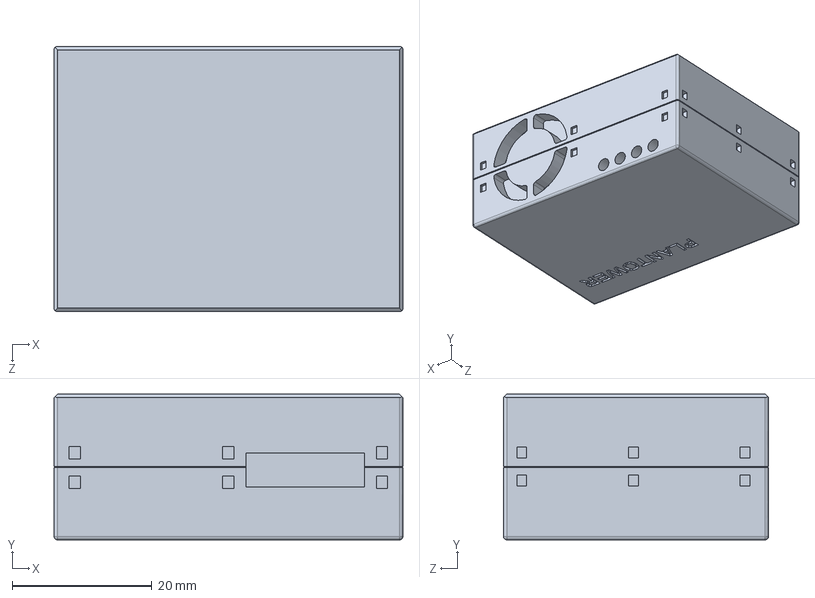
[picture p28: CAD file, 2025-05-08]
Enclosure_Design/PMS5003.SLDPRT
50.0 x 20.9 x 38.0 mm

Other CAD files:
Enclosure_Design/PCB.SLDPRT

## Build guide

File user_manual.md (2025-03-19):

*Note: This user manual was created using the software markdown structure format (.md) as part of the overall user guide in the Capstone's GitHub repository. Once complete, the entire GitHub respository will be made public and intended to be used as the complete User Manual.*

<!-- Title and background information -->
# Raspberry Pi Mesh Network for Environmental Sensor Data Monitoring User Manual
**Course:** SEE 410W | SEE411
**Created by:** Pi-oneers Team (Micheal Chen, Nathaniel King, William Le, Tianna Sequeira)
**Submitted on:** March 30, 2025

**Client:** Stephen Makonin, SFU Computational Sustainability Lab
**Capstone Advisor:** Mina Xu, SEE Professor

## Table of Contents
1. [User Guide Overview](###userguide)
2. [Safety Considerations](###safety)
3. [Technical Specifications](###techspec)
4. [Prototype at a Glance](###prototype)
5. [Operating the Prototype](###operation)
6. [Maintenance](###maintenance)
7. [Troubleshooting](###troubleshoot)
8. [Team Member Contribution](###contribution)
9.  [References](###references)

<!-- Section 1: Overview -->
### User Guide Overview 
Our capstone project, an environmental data monitoring system, is an open-source software platform designed for users seeking to analyze their surroundings for sustainable development, health monitoring, or weather forecasting. The system is versatile and can be deployed indoors in residential or commercial spaces, as well as in outdoor or extreme environments such as greenhouses. Whether you are a beginner exploring home electronics or an experienced designer, this guide will help you develop and implement your own system.

This user guide provides an overview of the completed capstone prototype, as well as how you can adapt it to your own needs. It outlines key safety considerations, technical and operating specifications, and step-by-step instructions for setup and operation. Additionally, this guide includes troubleshooting procedures and maintenance guidelines to ensure optimal performance and reliability.

<!-- Section 2: Safety Section -->
### Safety Considerations 
<!-- Safety First – A list of safety features; any cautions that must be exercised by the user and operator -->
When operating the environmental data monitoring system, users must follow basic safety precautions to ensure both personal safety and the longevity of the prototype. As the system involves electrical components, proper handling of wiring and power connections is essential to prevent short circuits, electrical shocks, or potential fire hazards. Users should ensure all components are properly insulated and avoid exposing the system to moisture unless it has been adequately weatherproofed for outdoor deployment. Additionally, if the system is installed in an industrial or extreme environment, care must be taken to secure components against physical damage, overheating, or exposure to harsh elements. Regular inspections of wiring, sensors, and power supplies should be conducted to prevent failures. Lastly, when modifying or expanding the system, users should follow best practices for electronic assembly and software security to avoid damage or data breaches.

<!-- Section 3: Technical Specifications -->
### Technical Specifications 
<!-- Technical Specifications – Details of the design, including dimensions, weight, energy input/outputs -->

<!-- Section 4: Prototype -->
### Prototype at a Glance 
<!-- Prototype at a Glance – Orienting the user to the main features of the design; basic functions and considerations; instrumentation -->

<!-- Section 5: Prototype Operation -->
### Operating the Prototype 
<!-- Operating the Prototype – Detailed description of how each sub-component can be operated -->

<!-- Section 6: Maintenance -->
### Maintenance 
<!-- Maintenance – Frequency of service; elements needing service -->
The maintenance requirements for this prototype largely depend on the lifespan and durability of the physical components used. Since the core of the system is software-based, minimal upkeep is required as long as the hardware remains in proper working condition.

However, the environment in which the prototype is deployed plays a significant role in determining maintenance needs. For indoor applications, such as residential or commercial spaces, maintenance is relatively low. Routine checks should include ensuring proper power supply, securing sensor connections, and keeping components free from dust or debris that could affect performance.

In contrast, deployments in harsher environments—such as greenhouses, outdoor fields, or industrial settings may require more frequent maintenance. Exposure to varying weather conditions, humidity, dust, and potential physical impacts can degrade materials over time. Metal components may be susceptible to corrosion, enclosures may require additional sealing to prevent moisture ingress, and sensors may need regular calibration to maintain accuracy. In these cases, periodic inspections should be performed to check for wear and tear, clean or replace damaged parts, and ensure continued reliability.

Regular software updates and data integrity checks should also be part of the maintenance routine to prevent performance issues. Ensuring proper ventilation, securing cable connections, and protecting the system from power surges will further extend the lifespan of the prototype. By following these maintenance guidelines, users can maximize the efficiency and longevity of their environmental data monitoring system, regardless of where it is deployed.

<!-- Section 7: Troubleshooting -->
### Troubleshooting 
<!-- Troubleshooting – Describe common faults anticipated and ways of overcoming them -->
With many systems, it is expected for some faults to occur throughout the design process, and it is important to know how to address them. Below are some of the potential faults our team has identified:

##### Wi-Fi Disconnection
In some cases, users could experience a Wi-Fi disconnection, which can prevent data transmission. This may be caused by a weak or unstable Wi-Fi signal, incorrect network credentials, or the Raspberry Pi failing to detect the network. To resolve this, check if the Wi-Fi network is operational by testing with another device. Ensure the Raspberry Pi is within range of the router, repositioning it or using a Wi-Fi extender if necessary. Verify that the correct SSID and password are entered, and restart both the Raspberry Pi and the router to reset the connection. If using a static IP, confirm that the configuration settings are correct.
##### Electrical Wiring Disconnection
In some environments (especially those that are more humid), users may encounter is electrical wiring disconnection, which can result in the system failing to power on or sensors not receiving power. This may be due to loose or disconnected power cables, a faulty power adapter, or damaged wiring. To fix this, inspect all power connections and ensure they are securely plugged in. Test the power adapter with an alternate one if available and check the Raspberry Pi’s LED indicators to confirm it is receiving power. If external sensors are not functioning, ensure their power connections are intact. Additionally, using a multimeter can help detect voltage inconsistencies in the power lines.
##### Data Overload
If users are storing large data files or have expanded the system to include multiple sensors, the excessive data processing can cause slow performance or unresponsiveness. This typically occurs when too many sensors are active, the Raspberry Pi has limited RAM or storage, or high-frequency data logging is overwhelming the system. To address this, reduce the data collection rate to lower processing demands, limit the number of active sensors, or distribute processing across multiple Raspberry Pis. Regularly clearing unnecessary data logs can free up storage space, while using a high-endurance microSD card or external storage can prevent write fatigue. Optimizing the software to filter and process only necessary data can also improve performance.
##### Sensor Malfunctions
If the sensors are not initialized properly, users may also encounter sensor malfunctions or incorrect readings, where sensor outputs fluctuate, display errors, or stop working entirely. This can be due to loose or incorrect wiring connections, calibration drift, or exposure to extreme environmental conditions. To resolve this, verify that all sensor connections match the wiring diagram and check for physical damage, replacing faulty sensors as needed. Recalibrating sensors according to the manufacturer’s instructions can improve accuracy. Additionally, ensuring sensors are not exposed to conditions beyond their rated specifications and restarting the system to refresh sensor readings may help.
##### Microcontroller Boot
In rare cases, the Raspberry Pi may not display or respond. This can result in an insufficient power supply, or hardware failure. To troubleshoot, try booting with a the Raspberry Pi again by using the BOOTSEL button. Ensure the power supply meets the recommended voltage and current requirements, as an underpowered device may fail to start properly. If the Raspberry Pi appears physically damaged, such as having broken ports or burned components, replacing the board may be necessary. If the issue persists, testing with another Raspberry Pi unit can help determine if the problem lies with the hardware.

c
Below is a list of each members contributions for this portion of the capstone project. 

<!-- Table for Team Member Contributions -->
| Team Member | Contributions |
| ---|---|
|Micheal| <li> Finalized PCB Design <br> <li> Ordered Final Components |
|Nathaniel | <li> Developed database, storage and collector node code <br> <li> Documentation and Writing User Manual |
| Tianna | <li> Developed User Website Interface (front end code) <br> <li> Documentation and writing User Manual |
| William | <li> 3D Model Printing |

### References

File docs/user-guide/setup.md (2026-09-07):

# Setup

This guide explains how to assemble a small openCollector deployment. openCollector is currently a research prototype, so validate the complete system before using it for unattended monitoring.

## Before You Begin

You will need:

- A computer capable of running QuestDB and the Python storage service.
- One or more collector devices, such as a Raspberry Pi Pico W, and supported sensors.
- Network connectivity from every collector to QuestDB's HTTP endpoint and from the storage service to QuestDB's PostgreSQL endpoint.
- [Git](https://git-scm.com/), [Python](https://www.python.org/) 3.13 or later, and the [uv package manager](https://docs.astral.sh/uv/getting-started/installation/) for a manual installation.
- Docker and an editor with Development Containers support if you use the repository's development container.

## Identify Devices

First decide which devices will host each service.

- **Collector** nodes may be deployed on any device capable of reading the sensors and reaching the database. The collector is designed to support MicroPython devices such as the Raspberry Pi Pico W.
- The **storage** node may run on any computer capable of hosting a Python web server. It may share a computer with QuestDB.
- **QuestDB** may run beside the storage node or on another host. Size that host for the required data retention, collector count, and sampling frequency.

See [Supported Sensors](./collector/sensors.md) before selecting hardware.

### Network Considerations

Collectors send data to QuestDB over HTTP, normally on port `9000`. The storage service reads QuestDB using the PostgreSQL wire protocol, normally on port `8812`, and serves the browser interface over HTTP, normally on port `8000`. If the components are on separate devices, use the database host's LAN address rather than `localhost` and allow only the required ports through the host firewall.

The browser and REST interfaces enforce HTTP Basic authentication by default, but Basic credentials are safe only when transported over HTTPS. Use the production Caddy configuration or another HTTPS reverse proxy before exposing the interface outside a trusted network. Keep QuestDB's ingestion port limited to intended collector networks.

## Deploy QuestDB and the Storage Node

The storage service creates the openCollector tables when it first starts and successfully connects to QuestDB. Start QuestDB before starting the storage service.

### Development Container (Recommended for Evaluation)

The repository includes a development Compose configuration that starts QuestDB and a Python development container together. It is intended for local development, not production deployment.

1. Clone `https://github.com/compsust/openCollector`.
2. Open the repository in an editor that supports [Development Containers](https://containers.dev/), then choose **Reopen in Container**. Docker starts both the `open-collector` and `database` services, and `uv sync` installs the Python dependencies.
3. Copy `storage/.env.example` to `storage/.env` and set `QUESTDB_HOST=database`, `QUESTDB_USER=pguser`, and `QUESTDB_PASSWORD=quest` to match `.devcontainer/docker-compose.yml`.
4. In the development-container terminal, start the storage service:

    ```bash
    cd /workspace/storage/src
    uv run litestar run --app app:app --host 0.0.0.0 --port 8000
    ```

5. Forward port `8000` in your editor and open `http://localhost:8000/dashboard`.

QuestDB's web console is available on port `9000`. Stop the Compose project when it is no longer needed. Database data is retained under `.devcontainer/data/`.

### Manual Installation on One Host

1. Install and start QuestDB using its [installation guide](https://questdb.com/docs/quick-start/). Configure an HTTP user for collectors and a PostgreSQL user for the storage service.
2. Clone the repository and install the storage dependencies:

    ```bash
    git clone https://github.com/compsust/openCollector.git
    cd openCollector/storage
    uv sync --active
    cp .env.example .env
    ```

3. Edit `.env`. For a database on the same host, use `QUESTDB_HOST=localhost`; set the PostgreSQL username and password to the values configured in QuestDB. See [Storage Config](./storage/config.md) for every setting.
4. Start the service from the source directory:

    ```bash
    cd src
    uv run litestar run --app app:app --host 0.0.0.0 --port 8000
    ```

5. Open `http://localhost:8000/dashboard`. On first startup, check the terminal for database connection or table-creation errors.

### Production Compose Deployment

The `deploy/compose.yaml` stack runs a pinned QuestDB release, the openCollector storage image, and Caddy as an HTTPS reverse proxy. It includes persistent volumes, health checks, restart policies, an unprivileged read-only storage container, and required credentials.

1. Point a DNS name at the server and allow inbound ports `80` and `443`. Keep port `9000` bound to loopback unless collectors must reach it; if they do, set `QUESTDB_BIND_ADDRESS` to the appropriate host address and restrict the port with a firewall.
2. Copy `deploy/.env.example` to `deploy/.env` and replace every example credential with a different long, randomly generated value. Set `DOMAIN` to the public DNS name.
3. Build and start the stack from the repository root:

    ```bash
    docker compose --env-file deploy/.env -f deploy/compose.yaml up -d --build
    docker compose --env-file deploy/.env -f deploy/compose.yaml ps
    ```

4. Open `https://YOUR_DOMAIN/dashboard` and enter `INTERFACE_USER` and `INTERFACE_PASSWORD`.
5. Back up the `questdb-data` Docker volume and the deployment `.env` through secure, access-controlled processes.

For a non-container storage deployment, `deploy/opencollector-storage.service` is a hardened systemd starting point. Adjust its paths and create `/etc/opencollector/storage.env` with permissions readable only by the service account.

### Separate Database and Storage Hosts

Install QuestDB on the database host and the storage service on the application host using the manual steps above. In `storage/.env`, set `QUESTDB_HOST` to the database host name or IP address. In each collector's `config.json`, set `upload.host` to that same reachable address and `upload.port` to QuestDB's HTTP port. Confirm connectivity to ports `8812` and `9000` before troubleshooting the application.

## Assemble Collectors

The wiring and physical placement depend on the deployment. The repository includes an optional PCB for connecting multiple sensors to a Raspberry Pi Pico W and a matching enclosure. See [PCB and Enclosure](./collector/pcb.md) and verify every connection against the sensor documentation before applying power.

## Configure Collectors

Copy `collector/src/config.example.json` to `collector/src/config.json`, assign unique collector and sensor UUIDs, enter the Wi-Fi and QuestDB connection details, and describe each attached sensor. See [Collector Config](./collector/config.md) for all properties and [Supported Sensors](./collector/sensors.md) for sensor-specific pins and attributes.

Do not commit `config.json`: it can contain Wi-Fi and database credentials.

## Deploy Collectors

Collector deployment uses the packaging and flashing scripts in `scripts/`.

1. Install a current MicroPython build on the target board using the board vendor's instructions.
2. Install the host tool with `python -m pip install mpremote`.
3. Connect one Pico W over USB and run `./scripts/flash_pico.sh collector/src/config.json`. Pass an `mpremote` device identifier as the second argument if auto-detection is ambiguous.
4. The script validates the configuration, creates `dist/pico.zip`, copies the collector and common packages plus a boot `main.py`, and resets the board.
5. Connect the sensors while the board is unpowered, then power the collector and monitor its serial output.
6. Confirm that the collector and sensors appear on the dashboard and become `OPERATIONAL`. See [Troubleshooting](./troubleshooting.md) if they do not.

The **Pico W package** workflow creates a downloadable package on changes to the collector. The manually dispatched **Pico W hardware-in-the-loop** workflow flashes a physically attached board and runs one sensor polling cycle. The HIL workflow requires a suitably labelled, secured self-hosted runner; it cannot run on GitHub-hosted hardware.

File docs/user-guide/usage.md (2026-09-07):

# Usage

This page explains how to monitor an openCollector deployment through the browser and REST interfaces.

## Data Display

### Data Types

openCollector stores two categories of information from a collector:

1. **Records** are numerical readings measured by a sensor. A single sensor can produce several record types, such as temperature and humidity.
2. **Errors** describe exceptions raised while initializing or reading a sensor, or while the collector performs other work.

### Node Status

Status gives a quick indication of a collector or sensor's recent activity:

1. White — `UNKNOWN`: no records or errors have been received.
2. Yellow — `DROPPED`: no recent records or errors have arrived. The timeout is the collector's `polling_interval` multiplied by the storage node's `ACTIVE_DEVICE_POLLING_THRESHOLD`.
3. Red — `ERROR`: the most recent event is an error rather than a numerical record.
4. Green — `OPERATIONAL`: numerical data has arrived more recently than an error.

A collector's status is derived from its own errors and the status of its sensors. Use the status as a prompt to investigate, not as proof that every reading is accurate. See [Storage Config](./storage/config.md#data-display) to change the dropped-device threshold.

### Errors

Sensor errors occur while reading a sensor. The current collector provides best-effort, at-most-once delivery: each report is submitted once during its polling cycle. If an upload fails, the exception is printed locally and polling continues. The failed report is neither buffered nor retried, so measurements produced during a communication failure are permanently absent from QuestDB. Sensor polling errors can be stored when communication is available, but communication failures themselves are not persisted remotely.

Durable offline buffering and bounded retry are future work. Do not rely on this research prototype as the only copy of safety-critical data.

## Web Interface

Start the storage service, then open its address in a browser (for a local default deployment, `http://localhost:8000`). The navigation bar links to the home page, dashboard, authentication information, and project information.

### Authentication

Browser and REST routes use HTTP Basic authentication when `AUTH_ENABLED=true`, which is the default. Enter `INTERFACE_USER` and `INTERFACE_PASSWORD` when prompted. Basic authentication does not encrypt traffic, so production deployments must use HTTPS. The production Compose configuration includes Caddy for TLS termination.

### Dashboard

Open `/dashboard` to see the deployment overview. The summary reports total collectors, sensors, records, and errors. The collector list shows each sensor's current status and latest values.

To graph a measurement:

1. Select a collector.
2. Select one of its sensors.
3. Select the record type to plot.
4. Use the refresh button to pause or resume automatic graph updates. Pause updates before zooming or inspecting the graph so a refresh does not replace the current view.

The page refresh interval is controlled by `INTERFACE_REFRESH_SECONDS` in the storage configuration. An empty selector usually means metadata for that collector or sensor has not reached the database yet.

### Collector Page

Select a collector name on the dashboard, or open `/collectors/{collector_id}`, to view device metadata, totals, latest sensor values, sensor status, and recent errors. Select a sensor card to open its detail page.

### Sensor Page

Open `/collectors/{collector_id}/sensors/{sensor_id}` to view the sensor type, current status, recent records, and recent errors. The page displays the first 100 records and 50 errors returned by the detail query.

## REST API

The storage service exposes a read-only JSON API under `/api/query`. The generated OpenAPI schema is also included in this documentation under [OpenAPI](./storage/openapi.md).

### Authentication

The REST API uses the same HTTP Basic credentials as the browser. Always use HTTPS outside a trusted local network.

### Endpoints

- `GET /api/query/summary` returns totals and status information for the deployment.
- `GET /api/query/collectors/{collector_id}` returns collector details. Supply `errors_page` and `errors_page_size` query parameters.
- `GET /api/query/collectors/sensors/{sensor_id}` returns sensor records and errors. Supply `records_page`, `records_page_size`, `errors_page`, and `errors_page_size` query parameters.

For example:

```bash
curl --user "admin:YOUR_PASSWORD" "http://localhost:8000/api/query/summary"
```

```bash
curl --user "admin:YOUR_PASSWORD" "http://localhost:8000/api/query/collectors/COLLECTOR_ID?errors_page=1&errors_page_size=25"
```

Use IDs from the collector configuration or a previous API response. Pagination values must be positive integers. API routes under `/api/command` are reserved for future functionality and currently expose no operations.

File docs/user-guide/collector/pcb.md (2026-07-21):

# PCB and Enclosure

The optional interface PCB and enclosure provide a tidy way to mount a Raspberry Pi Pico W with the sensors used by the original OpenCollector greenhouse prototype. They are hardware design sources, not a requirement for running the software; supported sensors may also be wired directly or mounted on a custom carrier.

## PCB

The latest design in the repository is `PCBs/Sensor Interface PCB REV4`. It contains the Altium project, schematic (`Sheet1.SchDoc`), board layout (`PCB.PcbDoc`), a STEP model (`PCB.step`), and generated fabrication layers under `Project Outputs for Capstone PCB Project`.

Before ordering or assembling a board:

1. Open the revision 4 project in compatible PCB-design software and review the schematic, footprints, board outline, and design rules.
2. Generate a fresh fabrication package from the source project and compare it with the checked-in output files. The repository does not provide a single, release-qualified manufacturing archive or bill of materials.
3. Confirm connector pin order, voltage levels, and current requirements against the exact Pico W and sensor modules you purchased. Similar modules can use different connectors or pin orders.
4. Assemble and inspect the board before inserting the Pico W or sensors. Check for shorts between power and ground with the board unpowered.
5. Configure the collector GPIO values to match the assembled wiring. The PCB does not automatically configure the software; see [Collector Config](./config.md) and [Supported Sensors](./sensors.md).

Revision 3 is retained for reference. Use revision 4 for new work unless you have already validated revision 3 hardware. These files are prototype engineering artifacts and have not been documented as a certified or production-ready hardware release.

## Enclosure

The `Enclosure_Design` directory contains SolidWorks part and assembly files for the prototype enclosure and models of the PCB and sensors. Open `Assem1.SLDASM` to inspect the complete assembly. The repository does not currently include ready-to-print STL or 3MF exports.

To manufacture an enclosure:

1. Open the assembly in a compatible CAD application and verify that all referenced parts resolve.
2. Check clearances against the assembled revision 4 PCB, connectors, cables, and the exact sensor modules in use.
3. Export the printable enclosure parts—not the PCB or sensor reference models—to STL or 3MF using appropriate mesh tolerances.
4. Print a low-cost fit test before the final enclosure. Confirm access to power, programming, ventilation, and sensor openings.
5. Mount components without stressing the PCB or cables. Keep air-quality, temperature, humidity, and light sensors exposed as required by their manufacturers.

Enclosure material, ventilation, direct sunlight, condensation, and heat from the electronics can bias environmental readings. Place the collector where air can circulate and validate measurements against a trusted reference instrument after installation.

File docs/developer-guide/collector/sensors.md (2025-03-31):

# Sensors

For documentation on which sensors are currently supported and how to configure them, see the [User Guide](../../user-guide/collector/sensors.md) sensors page.

See the [Sensor Reference](./reference/sensors.md) for documentation on the sensor-related source code.

## Datastructure

Each sensor returns data of the type `SensorData`, which can be found in the file `common/src/common/datastructure.py`. This is a dictionary with values of numerical type and keys of type `RecordID` which is a union of all values of `record_id` found in the sensor metadata. See [Update the Sensor Metadata](#update-the-sensor-metadata) for more information.

## Adding Sensor Support

The following is a list of instructions for adding support for a new sensor. Before starting, first verify the following:

1. The existing sensor interface contained withing the [Sensor Reference](./reference/sensors.md) and the capacities for sensor configuration outlined in the [Config](../../user-guide/collector/config.md) will be able to support the sensor. If the sensor requires any dynamic runtime configuration that can't happen within a single Python module, it may not be able to work.
2. The code for reading from the sensor that you plan to use is compatible with Micropython.

### Update the Sensor Metadata

The first step is to add the sensors to the list of recognized sensors. In the common module, the file `common/src/common/sensors.py` stores this metadata, and it is split into three parts:

1. The `SensorCodeEnum` is an enumerated string where each supported sensor gets its own code. It is used to identify the type of sensor when data is uploaded to the database.
2. The `sensor_metadata` dictionary maps values of `SensorCodeEnum` to a typed dictionary of the type `SensorMetadata`. The `SensorMetadata` dictionary has the following attributes:
    - `name`: A human-readable string name for the sensor, used in the display of the sensor type in the interface. Usually, this will be identical to the value of `SensorCodeEnum`, but in case the sensor code is not what is desired to have displayed as the name of the sensor type, the `name` attribute allows changing that.
    - `values`: A list of `SensorValueMetadata` typed dictionaries, which specify the structure of numerical data returned by the sensor and have the following attributes:
        - `name`: A human readable name of the sensor value. Used for display of the sensor data in the interface. For example, "Temperature" or "CO2 Concentration".
        - `record_id`: The string key under which this sensor value will be stored in the `SensorData` dictionary returned by this sensor. For example, if a sensor has two `SensorValueMetadata`, one with a `record_id` of `"temperature"` and the other with a `record_id` of `"humidity"` we can expect the `SensorData` dictionary returned by the sensor to have the structure `{"temperature": 20, "humidity": 80}`. It is important that `record_id`s be **unique amongst the other `SensorValueMetadata` for a particular sensor type** as a dictionary can only have one value per key.
        - `unit`: A string representing the unit system that the measured value is in. Used in the interface to display the data with the proper unit.
3. The `RecordID` type is a union of strings which contains all values of `record_id` found in the `sensor_metadata` dictionary. It is used for type hinting that a value is one of the keys expected within `SensorData`. Currently, this is defined as a union of literal strings with the `Literal` type, but in the future it would be best if this were derived directly from the `sensor_metadata` dictionary.

With this in mind, adding a new sensor to this metadata requires the following:

1. Add a new, unique code to `SensorCodeEnum`.
2. Add a new entry to the `sensor_metadata` dictionary, ensuring that the full structure of `SensorData` the sensor will return is accounted for with correct values of `SensorValueMetadata`.
3. If any `record_id`s were added to the metadata that weren't in there before, add them to the `RecordID` type.

### Implement the `SensorDriver`

The concrete implementations of the `AbstractSensorDriver` interface are located in the folder `collector/sensors/drivers`. The interface itself is very simple and only has two functions:

1. `__init__(self, config: SensorConfig)` intakes the `SensorConfig` object from the SensorManager and takes care of any required initialization of variables or sub-drivers. Note that both the `gpio` and `attributes` dictionaries on the config aren't previously validated, so this function may also ensure that all required keys are present.
2. `poll() -> SensorData` executes the code required to retrieve data from the sensor and returns a dictionary with the keys as configured in `sensor_metadata`. If this function fails, it should raise an exception, with a helpful error message, as the exception string is what is uploaded to the database.

Additionally, the file `collector/sensors/sensor_codes.py` contains the `sensor_drivers` dictionary, which maps all possible values of `SensorCodeEnum` to their associated drivers.

Therefore, to add a new sensor, the following steps are required:

1. Create a new `.py` file in the `collector/sensors/drivers` directory, and create a class called `<SensorType>SensorDriver` which implements the `AbstractSensorDriver` class.
2. Add the class to the `sensor_drivers` dictionary in the `collector/sensors/sensor_codes.py` file with the correct value of `SensorCodeEnum` as the key.

### Update the Documentation.

Finally, the following steps are required to add the supported sensor to the documentation:

1. Add the newly added value of `SensorCodeEnum` to `docs/user-guide/collector/sensord.md` with a description of the type of sensor and a link to the sensor page.
2. Add a new section under the [Configurations header](../../user-guide/collector/sensors.md#configurations) for the sensor. The section should have 3 sub-sections:
    1. The GPIO section documents each key in the `gpio` configuration object for the `SensorConfig` for this sensor.
    2. The Extra Attributes section documents each key in the `attributes` configuration object for the `SensorConfig` for this sensor.
    3. The Output Structure section documents the expected structure of `SensorData` for this sensor and should match the configuration in `sensor_metadata`.
3. Add an example configuration for this sensor to the `config.example.json` document located in `collector/src`.

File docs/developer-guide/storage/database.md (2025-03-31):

# Database Structure

```mermaid
classDiagram
    class UploadedOnStart["Uploaded on startup"]
    class UploadedOnPoll["Uploaded every poll"]

    UploadedOnStart --> CollectorMetadata
    UploadedOnStart --> SensorMetadata
    UploadedOnPoll --> Record
    UploadedOnPoll --> Error

    class CollectorMetadata {
        timestamp: TIMESTAMP
        collector_id: SYMBOL
        collector_name: VARCHAR
        device_model: VARCHAR
        polling_interval: INT
    }
    class SensorMetadata {
        timestamp: TIMESTAMP
        collector_id: SYMBOL
        sensor_id: SYMBOL
        sensor_code: INT
        sensor_name: VARCHAR
    }
    class Record {
        timestamp: TIMESTAMP
        collector_id: SYMBOL
        sensor_id: SYMBOL
        record_id: SYMBOL
        value: DOUBLE
    }
    class Error {
        timestamp TIMESTAMP
        collector_id: SYMBOL
        sensor_id: SYMBOL
        error_message: VARCHAR
    }
```

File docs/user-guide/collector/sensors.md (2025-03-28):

# Sensors

This page contains information on the types of sensors that are supported and their associated configuration values.

For information on how to add more supported sensors to the software, see the page in the [Developer Docs](../../developer-guide/collector/sensors.md).

## Supported Sensors and Codes

The following table outlines the sensors that are supported by the collector node software. Node that the values in the *Sensor Code* column are the values that are accepted by the `sensor_code` value in the sensor configuration object. 

| Sensor | Type | Sensor Code |
| --- | --- | --- |
| [DHT20](https://www.adafruit.com/product/5183) | Temperature & Humidity | `"DHT20"` |
| [TSL2561](https://cdn-shop.adafruit.com/datasheets/TSL2561.pdf) | Luminosity | `"TSL2561"` |
| [PMS5003](https://www.adafruit.com/product/3686) | Air Quality | `"PMS5003"` |
| [MH-Z19B](https://www.winsen-sensor.com/d/files/infrared-gas-sensor/mh-z19b-co2-ver1_0.pdf) | CO2 | `"MHZ19B"` |

## Configurations

The following sections outline the required structure of the `gpio` and `attributes` section of the sensor config for each sensor type. It also includes the structure of data which is output by the sensor.

### DHT20

The DHT is a compact temperature and humidity sensor which communicates via I2C.

#### GPIO

The following is the structure and allowed keys of the `gpio` object within the sensor config object for this sensor.

| Key | Description |
| --- | --- |
| `"SCL"` | The GPIO pin used for SCL. |
| `"SDA"` | The GPIO pin used for SDA. |

#### Extra Attributes

There are no extra attributes used by this sensor.

#### Output Structure

The following is the structure of the data which this sensor will upload to the database.

| Value | Unit | Description |
| --- | --- | --- |
| Temperature | °C | The temperature read by the sensor in celsius. |
| Humidity | % | The humitidy read by the sensor in %. |

### TSL2561

The TSL2561 is a digital light sensor which communicates via I2C.

#### GPIO

The following is the structure and allowed keys of the `gpio` object within the sensor config object for this sensor.

| Key | Description |
| --- | --- |
| `"SCL"` | The GPIO pin used for SCL. |
| `"SDA"` | The GPIO pin used for SDA. |

#### Extra Attributes

There are no extra attributes used by this sensor.

#### Output Structure

The following is the structure of the data which this sensor will upload to the database.

| Value | Unit | Description |
| --- | --- | --- |
| Luminosity | Lux | The luminosity read by the sensor in lux. |

### PMS5003

The PMS5003 is a digital air quality sensor which communicates through UART. It reports the concentration of PM1.0, PM2.5, and PM10.

#### GPIO

The following is the structure and allowed keys of the `gpio` object within the sensor config object for this sensor.

| Key | Description |
| --- | --- |
| `"TX"` | The GPIO pin used for UART TX. |
| `"RX"` | The GPIO pin used for UART RX. |

#### Extra Attributes

The following is the structure and allowed keys of the `attributes` object within the sensor config object for this sensor.

| Key | Description |
| `"baudrate"` | The baudrate used for configuring UART. |

#### Output Structure

The following is the structure of the data which this sensor will upload to the database.

| Value | Unit | Description |
| --- | --- | --- |
| Particulate Matter Concentration 1.0 | PM1.0 | The PM1.0 read by the sensor. |
| Particulate Matter Concentration 2.5 | PM2.5 | The PM2.5 read by the sensor. |
| Particulate Matter Concentration 10 | PM10 | The PM10 read by the sensor. |

### MH-Z19B

The MH-Z19B is a digital CO2 sensor which communicates through UART.

#### GPIO

The following is the structure and allowed keys of the `gpio` object within the sensor config object for this sensor.

| Key | Description |
| --- | --- |
| `"TX"` | The GPIO pin used for UART TX. |
| `"RX"` | The GPIO pin used for UART RX. |

#### Extra Attributes

The following is the structure and allowed keys of the `attributes` object within the sensor config object for this sensor.

| Key | Description |
| `"baudrate"` | The baudrate used for configuring UART. |

#### Output Structure

The following is the structure of the data which this sensor will upload to the database.

| Value | Unit | Description |
| --- | --- | --- |
| CO2 Concentration | PPM | The CO2 concentration read by the sensor in parts per million. |

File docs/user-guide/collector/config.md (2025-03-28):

# Collector Config

Collector nodes are configured through a JSON file located in the collector project repository. After cloning the repostitory, the config file can be found at the `config.json` file in `collector/src` directory of the repository. Note that `json` is used instead of `yaml` due to increased compatibility with *micropython*.

Within the `config.json` file are several sections:

- A root-level section for properties relating to the collector node itself.
- A device section for properties relating to the device the collector is being run on.
- An upload section for properties relating to how the collector will establish a connection to the database.
-  A sensor section which contains a list of objects each representing a sensor that is connected to the node.

On startup, the config file is parsed by the collector and used for initialization. If any errors are detected in the configuration, such as missing values or 

## A Note on IDs

In order for collectors and sensors to be indentified as unique nodes by the interface, they need to have unique IDs. Since communication between the collector and storage nodes is one-way, collector nodes have no way of verifying that their IDs are unique or of being assigned unique IDs. To get around this, UUIDs are used as collector and sensor IDs to prevent collision between different sensors.

Due to the lack of support for Python's `uuid` module in micropython, UUIDs must be generated and placed into the configuration files manually. An [online generator](https://www.uuidgenerator.net/version4) may be used to do this. In the future, a Python script which scans the `config.json` file and adds UUIDs automatically before deployment may be created to automate this task.

## Properties

The following are the properties set in `config.json`

### Root Properties

The following are the properties set at the root of the `JSON` object.

| Key | Type | Example | Required | Description |
| --- | --- | --- | --- | --- |
| `collector_id` | `string` | See [here](https://www.uuidgenerator.net/version4) for generating UUIDs | True | The ID used to identify the collector node within the database. Must be unique amongst all collector and sensor IDs in the database. |
| `node_name` | `string` | `"Greenhouse Collector 1"` | True | A human-readable descriptive name for the collector node. It doesn't have to be unique, but it should be to prevent confusion with other nodes. |
| `polling_interval` | `integer` | `1000` | True | The number of miliseconds between attempts by the collector node to read and upload data from its sensors. |
| `ssid_name` | `string` | `"network_name"` | False | The name of the SSID the node should connect to. If defined, the node will attempt to open a LAN connection to this SSID using the `network` module. If the runtime environment isn't micropython, meaning the network configuration is likely defined elsewhere, this should not be included. |
| `ssid_password` | `string` | `"network_password"` | False | The password of the SSID the node should connect to. If `ssid_name` is defined but this property isn't, an error will be thrown. |

### Device Properties

The following are the properties set on the `device` object in the `config.json` file.

| Key | Type | Example | Required | Description |
| --- | --- | --- | --- | --- |
| `model` | `string` | `"Raspberry Pi Pico W"` | True | A human-readable identifying name for the type of device the collector node is being run on. |
| `allowed_gpio` | `integer[]` | `[2, 4, 25]` | True | A list of usable values of GPIO pins for this device. This list is used to validate configured sensors. For example, if a sensor specifies that it requires the use of GPIO pin `3`, but `3` is not a value that is contained within this list, an error will be thrown. |
| `requires_micropython` | `boolean` | `false` | True | If true, the collector will validate that it is being run within a micropython runtime environment, and will throw an error if not. |

### Upload Properties

The following are the properties set on the `upload` object in the `config.json` file. See the [QuestDB REST](https://questdb.com/docs/reference/api/rest/) documentation for more information on the HTTP interface used by the collector node. 

| Key | Type | Example | Required | Description |
| --- | --- | --- | --- | --- |
| `host` | `string` | `"localhost"` | True | The URI at which the QuestDB instance in use is exposing itself. Note that this should not include `http://` as that is added by the collector node as it parses its configuration. |
| `port` | `integer` | `9000` | True | The port at which the HTTP interface is exposed. Note that this is a different port than QuestDB uses for other interfaces. By default it is `9000`. |
| `user` | `string` | `"node_user"` | True | The username configured in QuestDB for [HTTP Basic authentication](https://questdb.com/docs/reference/api/rest/#authentication-in-questdb-open-source). |
| `password` | `string` | `"node_password"` | True | The password configured in QuestDB for [HTTP Basic authentication](https://questdb.com/docs/reference/api/rest/#authentication-in-questdb-open-source). |

### Sensor Properties

The sensor properties is an array of `JSON` objects set on the `sensors` key in the `config.json` file. For each object in this array, the collector node will initialize an object representing a sensor of the configured type, and will attempt to pull data from it. Thus, to add a sensor that is supported by the software, a new object must be added to this array.

A list of supported sensors is contained within the [Sensors](./sensors.md) page.

To accomodate configuration that is unique to a sensor and can't be generalized to a common configuration object, the `attributes` key in the sensor configuration is a flexible type which can accept different values depending on the type of sensor. The individual sensor pages within the [Sensors](./sensors.md) page outline the structures of these objects.

| Key | Type | Example | Required | Description |
| --- | --- | --- | --- | --- |
| `sensor_id` | `string` | See [here](https://www.uuidgenerator.net/version4) for generating UUIDs | True | The ID used to identify the collector node within the database. Must be unique amongst all collector and sensor IDs in the database, not unique amongst the sensors of this node. |
| `sensor_code` | `"enumerated string"` | `"DHT20"` | True | A string used to identify the type of sensor configured by this sensor config. It is important that the sensor code matches that of one of the supported sensors. Refer to the [Sensors](./sensors.md) page for a list of supported sensors and their associated values of `sensor_code`. |
| `name` | `string` | `"Greenhouse Temperature 1"` | True | A human-readable descriptive name for the sensor. It doesn't have to be unique, but it should be to prevent confusion with other sensors. |
| `gpio` | `object with string keys and integer values` | `{"uart_tx": 21, "uart_rx": 22}` | True | An object where the keys are names of pin functions used by the sensor and the values are GPIO numbers to assign that function to. This is used to match the collector node's config with how the sensor is physically wired up. It is important that the keys in this object match the keys expected by the sensor's configuration as detailed in the [Sensors](./sensors.md) page. It is also important that the values of the GPIO pins be included in the list of allowed pins, `allowed_gpio` as contained within the `device` section of the config. Finally, the values of the GPIO pins must be correct given which functions are supported on which pins as dictated by the model of device the collector is running on. |
| `attributes` | `object with string keys and values of any type` | `{"baudrate": 9600}` | False | An object where the keys are names of configuration parameters and the values are the values of those parameters. This is a custom section of the configuration which will be different for every sensor. See the [Sensors](./sensors.md) page for configuring this section for each sensor. |

## Example Config

Below is an example of the configuration files with all values included. It is also included in the `collector/src` directory of the repository under the filename `config.example.json`, which is the expected location, so it may be copied, renamed `config.json`, and modified to suit the needs of a deployment. 

*Note: [you should generate your own UUIDs!](https://www.uuidgenerator.net/version4)*

```json
{% include "../../../collector/src/config.example.json" %}
```

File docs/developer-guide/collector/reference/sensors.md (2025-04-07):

# Sensor Reference

Source code reference for the collector sensor code.

## :::collector.src.sensors.manager.SensorManager

## :::collector.src.sensors.driver.AbstractSensorDriver

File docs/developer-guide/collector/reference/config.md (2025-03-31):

# Config Reference

Source code reference for the collector configuration code.

## ::: collector.src.config.datastructures.DeviceConfig

## ::: collector.src.config.datastructures.UploadConfig

## ::: collector.src.config.datastructures.SensorConfig

## ::: collector.src.config.datastructures.CollectorConfig

## ::: collector.src.config.manager.ConfigManager

## ::: collector.src.config.utils.get_attribute

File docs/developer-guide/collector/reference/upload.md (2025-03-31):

# Sensor Reference

Source code reference for the collector upload code.

## :::collector.src.upload.manager.UploadManager

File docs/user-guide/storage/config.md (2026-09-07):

# Storage Config

Storage nodes are configured through an environment variable located in the `storage` folder in the root of the repository.

## Properties

The following are the properties set in `.env`

### QuestDB Connection

The following configuration values relate to connecting the storage node to the QuestDB instance.

| Value | Type | Default | Description |
| --- | --- | --- | --- |
| `QUESTDB_HOST` | `string` | `localhost` | The hostname at which QuestDB may be accessed. Do not include an `http://` or `https://` prefix. |
| `QUESTDB_PORT` | `integer` | `8812` | The port the QuestDB database's PostgreSQL may be accessed at. Note that this is the Postgres Wire Protocol port and is different from QuestDB's REST API port. |
| `QUESTDB_USER` | `string` | `pguser` | The username used to access the database. |
| `QUESTDB_PASSWORD` | `string` | `quest` | The password used to access the database. |
| `QUESTDB_DB_NAME` | `string` | `qdb` | The name of the QuestDB database to access using Postgres. |

### QuestDB Schema

The following configuration values relate to how QuestDB's schema is structured.

| Value | Type | Default | Description |
| --- | --- | --- | --- |
| `COLLECTOR_CAPACITY` | `integer` | `1024` | The total number of unique collector nodes to support on this database. For storing collector IDs, QuestDB's `SYMBOL` type is used, which maps string values to a range of integers, increasing storage efficiency. This parameter sets the maximum number of symbols which are supported in the column which stores collector IDs, and cannot be changed. See [here](https://questdb.com/docs/reference/sql/create-table/#symbols). |
| `SENSOR_CAPACITY` | `integer` | `16` | The total number of unique sensors per collector node to support on this database. For storing collector IDs, QuestDB's `SYMBOL` type is used, which maps string values to a range of integers, increasing storage efficiency. This parameter, multiplied by `COLLECTOR_CAPACITY`, sets the maximum number of symbols which are supported in the column which stores collector IDs, and cannot be changed. See [here](https://questdb.com/docs/reference/sql/create-table/#symbols). |

### Data Display

| Value | Type | Default | Description |
| --- | --- | --- | --- |
| `ACTIVE_DEVICE_POLLING_THRESHOLD` | `number` | `3` | For each collector, defines an interval equal to the `polling_interval` configuration value of the node times `ACTIVE_DEVICE_POLLING_THRESHOLD` past which, if there are no recent records or errors in the database, the collector node or sensor will be considered 'dropped', ie. not currently sending data. For example, given an `ACTIVE_DEVICE_POLLING_THRESHOLD` of 4, if a collector node has a `polling_interval` of 3000ms, and a sensor on that node has not uploaded any sensor data or errors for the past 3000ms * 4 = 12 seconds, that sensor will be considered 'dropped'. See the [Usage](../usage.md) page for more information on status. |

### Interface and Security

| Value | Type | Default | Description |
| --- | --- | --- | --- |
| `NODE_NAME` | `string` | `OpenCollector` | Human-readable name for the storage node. |
| `DEBUG` | `boolean` | `false` | Enables Litestar debug mode. Keep disabled in production. |
| `AUTH_ENABLED` | `boolean` | `true` | Enables HTTP Basic authentication for browser and REST routes. The health and static-file routes remain public. |
| `INTERFACE_USER` | `string` | `username` | Username for the browser and REST interfaces. Replace the example value. |
| `INTERFACE_PASSWORD` | `string` | `password` | Password for the browser and REST interfaces. Replace the example value and use HTTPS. |
| `INTERFACE_REFRESH_SECONDS` | `integer` | `1` | Dashboard refresh interval in seconds. |

## Example Config

Below is an example of the configuration files with all values included. It is also included in the `storage` directory of the repository under the filename `.env.example`, which is the expected location, so it may be copied, renamed `.env`, and modified to suit the needs of a deployment. 

```ini
{% include "../../../storage/.env.example" %}
```

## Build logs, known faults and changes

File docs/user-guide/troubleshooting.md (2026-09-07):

# Troubleshooting

Work from the database outward: first confirm QuestDB, then the storage service, network access, collector startup, and finally individual sensors. Record the exact command, timestamp, collector ID, sensor ID, and error message when asking for help.

## Database Problems

- Confirm QuestDB is running. For the production stack, run `docker compose --env-file deploy/.env -f deploy/compose.yaml ps` and inspect `docker compose --env-file deploy/.env -f deploy/compose.yaml logs database`.
- Use `QUESTDB_HOST=database` inside Compose; `localhost` inside the storage container refers to that container, not QuestDB.
- Match the storage service's PostgreSQL credentials and port `8812` to QuestDB's `QDB_PG_USER` and `QDB_PG_PASSWORD`.
- For collector uploads, match `upload.user` and `upload.password` to QuestDB's separate `QDB_HTTP_USER` and `QDB_HTTP_PASSWORD` and confirm port `9000` is reachable only from intended collector networks.

## Wi-Fi Problems

- Recheck `ssid_name` and `ssid_password`, including capitalization and spaces. Do not commit these values.
- Confirm the access point offers a compatible 2.4 GHz network for the Pico W.
- Attach a serial console during boot and look for association, DHCP, DNS, or timeout errors.
- Test near the access point and use the database host's IP address temporarily to distinguish DNS failure from general connectivity failure.

## Sensor Problems

- Disconnect power before changing wiring. Verify voltage, ground, connector orientation, and every GPIO against the exact module datasheet.
- Ensure `sensor_code`, GPIO names, baud rate, and other attributes match the [sensor guide](./collector/sensors.md).
- Test one sensor at a time with a short cable. Check placement, airflow, warm-up time, condensation, sunlight, and calibration against a reference instrument.
- An `ERROR` status means the latest sensor event was an exception. Open its detail page and compare the error timestamp with serial output.

## Status Problems

- `UNKNOWN`: no record or error has reached the database. Check startup, metadata upload, IDs, and database credentials.
- `DROPPED`: the newest event is older than `polling_interval × ACTIVE_DEVICE_POLLING_THRESHOLD`. Check power and networking; increase the threshold only if healthy uploads are occasionally slow.
- `ERROR`: the latest error is newer than the latest record. Fix the reported cause; a newer valid record returns the sensor to `OPERATIONAL`.
- `OPERATIONAL` with implausible data: status indicates recent software activity, not accuracy. Check clock, units, placement, and calibration.

## Authentication and TLS Problems

- A `401 Authentication required` response means the HTTP Basic credentials are missing or incorrect. Use `INTERFACE_USER` and `INTERFACE_PASSWORD`, not QuestDB credentials.
- Browsers cache Basic credentials. Close every window for the site or use a private window after changing a password.
- A `502` from Caddy usually means the storage container is unhealthy. Check `/health` and the storage logs.
- Certificate issuance requires `DOMAIN` to resolve to the server and inbound ports `80` and `443` to reach Caddy.

## Pico Packaging and Hardware Tests

- Install `mpremote`, connect one Pico W, and run `./scripts/flash_pico.sh path/to/config.json`.
- If the device is not found, run `mpremote connect list` and pass its device identifier as the second argument.
- The HIL workflow needs a physically secured self-hosted runner labelled `self-hosted`, `micropython`, and `pico-w`, plus a `PICO_CONFIG_JSON` repository secret.

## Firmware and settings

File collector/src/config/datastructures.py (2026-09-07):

from typing import Any

from common import SensorCodeEnum

from .utils import get_attribute


class DeviceConfig:
    """
    Configuration object which describes a type of device
    that the collector node runs on.

    Attributes:
        model: A string representing the type of device,
            for example "Raspberry Pi 3."
        requires_micropython: If true, the program will
            not enable a start unless it is being run in a
            micropython environment.
    """

    model: str
    requires_micropython: bool

    def __init__(self, config: dict[str, Any], micropython: bool):
        """
        Initializes the config and ensures the required attributes are present.

        Args:
            config: The device config object, ie. the
                dictionary contained within the "device" key in the config file.
            micropython: Whether the current environment is micropython
        """
        self.model = get_attribute(config, "model", "device")
        self.requires_micropython = get_attribute(
            config, "requires_micropython", "device"
        )

        if self.requires_micropython and not micropython:
            raise ValueError(
                f"The current device {self.model} requires micropython but the environment is not micropython."
            )


class UploadConfig:
    """
    Configuration object which describes a QuestDB target.

    Attributes:
        host: The database URL.
        port: The database port.
        user: The database username.
        password: The database password.
    """

    host: str
    port: str
    user: str
    password: str

    def __init__(self, config: dict[str, Any]):
        """
        Initializes the config and ensures the required attributes are present.

        Args:
            config: The upload config object, ie. the
                dictionary contained within the "upload" key in the config file.
        """
        self.host = get_attribute(config, "host", "upload")
        self.port = get_attribute(config, "port", "upload")
        self.user = get_attribute(config, "user", "upload")
        self.password = get_attribute(config, "password", "upload")


class SensorConfig:
    """
    Configuration object which describes a sensor.

    Attributes:
        sensor_id: An ID associated with the sensor.
        sensor_code: Associated with
            a specific implementation of AbstractSensorDriver.
        name: A descriptive name for the sensor.
        gpio: A dictionary where the values are
            GPIO pins which the sensor requires use of, and
            the keys are string identifiers. Used to validate
            that the configured GPIO pins match the allowed_gpio
            attribute of the device config.
        attributes: Any other attributes
            which are required to use the sensor.
    """

    sensor_id: str
    sensor_code: SensorCodeEnum
    name: str
    gpio: dict[str, int]
    attributes: dict[str, Any] | None

    def __init__(
        self,
        config: dict[str, Any],
        index: int,
    ):
        """
        Initializes the config and ensures the required attributes are present.

        Args:
            config: The sensor config object, ie. a
                dictionary contained within the "sensors" array in the config file.
            index: The index of the sensor config within the "sensors" array.
        """
        self.sensor_id = get_attribute(config, "sensor_id", f"sensor[{index}]")
        self.sensor_code = SensorCodeEnum[
            get_attribute(config, "sensor_code", f"sensor[{index}]")
        ]
        self.name = get_attribute(config, "name", f"sensor[{index}]")
        self.gpio = get_attribute(config, "gpio", f"sensor[{index}]")
        self.attributes = get_attribute(
            config, "attributes", f"sensor[{index}]", required=False
        )


class CollectorConfig:
    """
    Configuration object which describes the collector node device.

    Attributes:
        collector_id: An ID associated with the node.
        node_name: A name associated with the node.
        ssid_name: If defined, the device will attempt to connect
            to this SSID.
        ssid_password: If defined, the device will attempt to connect
            to this SSID.
        polling_interval: The number of miliseconds to wait
            between sensor polls. Must not be negative.
        device: The device config.
        upload: The configured upload target.
        sensors: All configured sensors.
    """

    collector_id: str
    node_name: str
    polling_interval: int
    ssid_name: str | None
    ssid_password: str | None
    device: DeviceConfig
    upload: UploadConfig
    sensors: list[SensorConfig]

    def __init__(
        self,
        config: dict[str, Any],
        device: DeviceConfig,
        upload: UploadConfig,
        sensors: list[SensorConfig],
    ):
        """
        Initializes the config and ensures the required attributes are present.

        Args:
            config: The config object, ie. the
                dictionary pulled from the config file.
            device: The parsed device config.
            upload: The parsed upload config.
            sensors: The parsed sensor configs.

        Raises:
            ValueError: Raised if the polling interval is a negative number.
        """
        self.collector_id = get_attribute(config, "collector_id", "config")
        self.node_name = get_attribute(config, "node_name", "config")
        self.polling_interval = get_attribute(config, "polling_interval", "config")
        self.ssid_name = get_attribute(config, "ssid_name", "config", required=False)
        self.ssid_password = get_attribute(
            config, "ssid_password", "config", required=False
        )
        self.device = device
        self.upload = upload
        self.sensors = sensors

        # Validate that polling_interval is not negative.
        if self.polling_interval < 0:
            raise ValueError("Cannot set a negative polling interval.")

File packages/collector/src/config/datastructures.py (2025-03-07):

from typing import Any

from common.src import SensorCodeEnum


def get_attribute_or_error(
    config: dict[str, Any], attribute: str, config_name: str
) -> Any:
    """
    Retrieves the attribute from the config, or
    raises an error if it does not exist.

    Args:
        config (dict[str, Any]): The config to retrieve from.
        attribute (str): The name of the attribute.
        config_name (str): The name of the config.

    Raises:
        ValueError: Raised if the attribute does not
            exist within the config.

    Returns:
        Any: The config attribute.
    """
    try:
        attribute = config["attribute"]
    except KeyError:
        raise ValueError(
            f"Config '{config_name}' missing required parameter '{attribute}'."
        )

    if attribute is None:
        raise ValueError(
            f"Config '{config_name}' missing required parameter '{attribute}'."
        )

    return attribute


class DeviceConfig:
    """
    Configuration object which describes a type of device
    that the collector node runs on.
    Attributes:
        model (str): A string representing the type of device,
            for example "Raspberry Pi 3."
        allowed_gpio (list[int]): A list of GPIO pins on the
            device that the collector node is able to access.
            Used to validate sensor configuration, ie., that the
            sensor is configured to a valid GPIO pin.
        requires_micropython (bool): If true, the program will
            not enable a start unless it is being run in a
            micropython environment.
    """

    model: str
    allowed_gpio: list[int]
    requires_micropython: bool

    def __init__(self, config: dict[str, Any], micropython: bool):
        """
        Initializes the config and ensures the required attributes are present.

        Args:
            config (dict[str, Any]): The device config object, ie. the
                dictionary contained within the "device" key in the config file.
            micropython (bool): Whether the current environment is micropython
        """
        self.model = get_attribute_or_error(config, "model", "device")
        self.allowed_gpio = get_attribute_or_error(config, "allowed_gpio", "device")
        self.requires_micropython = get_attribute_or_error(
            config, "requires_micropython", "device"
        )

        if self.requires_micropython and not micropython:
            raise ValueError(
                f"The current device {self.model} requires micropython but the environment is not micropython."
            )


class UploadConfig:
    """
    Configuration object which describes a QuestDB target.
    Attributes:
        name (str): A descriptive name for the target.
        host (str): The database URL.
        port (str): The database port.
        user (str): The database username.
        password (str): The database password.
    """

    name: str
    host: str
    port: str
    user: str
    password: str

    def __init__(self, config: dict[str, Any]):
        """
        Initializes the config and ensures the required attributes are present.

        Args:
            config (dict[str, Any]): The upload config object, ie. the
                dictionary contained within the "upload" key in the config file.
        """
        self.name = get_attribute_or_error(config, "name", "upload")
        self.host = get_attribute_or_error(config, "host", "upload")
        self.port = get_attribute_or_error(config, "port", "upload")
        self.user = get_attribute_or_error(config, "user", "upload")
        self.password = get_attribute_or_error(config, "password", "upload")


class SensorConfig:
    """
    Configuration object which describes a sensor.
    Attributes:
        sensor_id (str): An ID associated with the sensor.
        sensor_code (SensorCodeEnum): Associated with
            a specific implementation of AbstractSensorDriver.
        name (str): A descriptive name for the sensor.
        gpio (dict[str, int]): A dictionary where the values are
            GPIO pins which the sensor requires use of, and
            the keys are string identifiers. Used to validate
            that the configured GPIO pins match the allowed_gpio
            attribute of the device config.
        attributes (dict[str, Any]): Any other attributes
            which are required to use the sensor.
    """

    sensor_id: str
    sensor_code: SensorCodeEnum
    name: str
    gpio: dict[str, int]
    attributes: dict[str, Any]

    def __init__(
        self,
        config: dict[str, Any],
        index: int,
        allowed_gpio: list[int],
    ):
        """
        Initializes the config and ensures the required attributes are present.
        Also, validates that the configured GPIO pins match those specified in the
        device config.

        Args:
            config (dict[str, Any]): The sensor config object, ie. a
                dictionary contained within the "sensors" array in the config file.
            index (int): The index of the sensor config within the "sensors" array.
            allowed_gpio (list[int]): The allowed GPIO pins as configured in the device config.
        """
        self.sensor_id = get_attribute_or_error(config, "sensor_id", f"sensor[{index}]")
        self.sensor_code = get_attribute_or_error(
            config, "sensor_code", f"sensor[{index}]"
        )
        self.name = get_attribute_or_error(config, "name", f"sensor[{index}]")
        self.gpio = get_attribute_or_error(config, "gpio", f"sensor[{index}]")
        self.attributes = get_attribute_or_error(
            config, "attributes", f"sensor[{index}]"
        )

        # Validate that the configured GPIO pins are allowed on this device.
        for pin in self.gpio:
            if self.gpio[pin] not in allowed_gpio:
                raise ValueError(
                    f"Error when configuring sensor ID {self.sensor_id} with name {self.name}: gpio pin {self.gpio}, {self.gpio[pin]} not included in allowed gpio pins: {allowed_gpio}"
                )
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

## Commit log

2024-09-26 Adds initial structure for data structures and sensor system
2025-01-06 Environment setup (#2)
    * Adds devcontainer and uv
    * Adds dev dependencies
    * Fixes imports and adds some vscode extensions
    [manager.py]
2025-01-07 Further defined config and sensor initialization
2025-01-14 Add files via upload
    Added initial code to read out sensor data (not tested yet)
2025-01-22 MC updates to i2c devices
2025-01-31 Update DHT22 to DHT20, add all sensors
2025-02-14 Switches docker to questdb
2025-02-14 Add files via upload
    started folder for sensor libraries
2025-02-21 Modified CO2 and PM sensors
2025-02-22 Added sensor drivers
2025-02-28 Fixes issues, webserver runs
    [MHZ19B.py]
2025-03-07 added calls to sensor drivers
2025-03-14 The data insert script can run - just need to allow it to create the tables first.
2025-03-14 Update main.py with correct driver location
2025-03-18 PCB Final design
    [Capstone PCB Project REV 3.PrjPcb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]
2025-03-28 Beginning sensor documentation
2025-03-29 Adds instructions for adding new sensors
2025-04-03 fixed home button error and submit button on login page (goes to dashboard)
2025-04-04 added collector & sensor pages
2025-04-04 updated path in main to test sensor integration
2025-04-04 uart devices updated
2025-04-04 Modified sensor code to conform to interface
2025-04-04 Begins sensor timeline
2025-04-05 uart devices update
2025-04-07 Seperates python and micropython drivers
2025-04-07 Adds mock sensor
2025-04-07 Removes all sensor implementations from docs reference
2025-05-05 Update to MHZ19B to use PWM method
2025-05-05 new pcb revision
    [Capstone PCB Project REV 3.PrjPcb, Capstone PCB Project.PrjPcb, PCB.PcbDoc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]
2025-05-08 Rename the folder
    [Assem1.SLDASM, Cap.SLDPRT, DHT20.SLDPRT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]
2026-09-07 Complete camera-ready openCollector artifact
